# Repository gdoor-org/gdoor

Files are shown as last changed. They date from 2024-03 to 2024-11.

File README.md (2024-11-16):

<p align="center">
GDoor Logo
GDoor Hardware
</p>
<p align="center">
  https://gdoor-org.github.io/
</p>

_________________

The GDoor hardware adapter allows listening and controlling the bus and e.g. integrating a Gira door bell into a <b>smart home</b> like [Home Assistant](https://gdoor-org.github.io/documentation/homeassistant.html) or [openHAB](https://gdoor-org.github.io/documentation/openhab.html). It might serve as an DIY alternative to the Gira TKS-IP-Gateway. It supports the following features:

- (In development): Audio support via VOIP
- listening to the bus, e.g. to trigger notifications on mobile devices when a door bell button is pressed
- sending to the bus, e.g. to open the door

Receiving and sending video is currently neither supported nor plannend.

GDoor is a project to collect and document findings about the Gira Door System, all figured out by reverse engineering.
Contributions are welcome!

# Buy / DIY
Moved to the dedicated [page](https://gdoor-org.github.io/buy.html) on our homepage.

# Documentation / Home Automation
Moved to the dedicated [page](https://gdoor-org.github.io/documentation/getting-started.html) on our homepage.

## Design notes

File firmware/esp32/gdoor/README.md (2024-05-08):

# ESP32 Firmware
More information about the firmware are located on the
[GDoor Homepage](https://gdoor-org.github.io/documentation/firmware.html).

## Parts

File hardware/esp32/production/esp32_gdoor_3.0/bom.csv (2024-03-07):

Designator | Footprint | Quantity | Value | LCSC Part #
C1 | 0603 | 1 | 47n | C1622
C10 | 0603 | 1 | 1n | C1588
C11, C13, C15, C16, C5, C6, C7 | 0603 | 7 | 100n | C14663
C12, C14 | 0603 | 2 | 10u | C96446
C2, C4, C8, C9 | 0603 | 4 | 100p | C14858
C3 | 0603 | 1 | 10n | C57112
D1 | SOIC-4_4.55x3.7mm_P2.54mm | 1 | MB10S | C2488
J1 | anschlussklemme2x1 | 1 | Screw_Terminal_01x02 | C8385
Q1 | SOT-23 | 1 | MMBT5401 | C8326
Q2 | SOT-23 | 1 | MMBT2222A | C8512
R1, R20 | 0603 | 2 | 130k | C22795
R10, R15, R6 | 0603 | 3 | 18k | C25810
R11, R13, R2, R22 | 0603 | 4 | 10k | C25804
R12, R14 | 0603 | 2 | 2k4 | C22940
R16, R17, R5, R7 | 0603 | 4 | 5k1 | C23186
R18, R19, R3, R4 | 0603 | 4 | 82k | C23254
R21 | 0603 | 1 | 4k7 | C23162
R8, R9 | 0603 | 2 | 47k | C25819
U1 | SOT-353_SC-70-5 | 1 | TLV9351 | C4367425
U2, U3 | SOT-23-5 | 2 | LMV321 | C7972
U5 | SOT-89-3 | 1 | HT7533-1 | C14289

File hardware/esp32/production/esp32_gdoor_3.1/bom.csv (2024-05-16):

Designator | Footprint | Quantity | Value | LCSC Part #
C1 | 0603 | 1 | 47n | C1622
C11, C13, C15, C16, C17, C3, C5, C6, C7 | 0402 | 9 | 100n | C307331
C12, C14 | 0603 | 2 | 10u | C96446
C19, C20 | 1210 | 2 | 100u | C15008
C2, C4, C8, C9 | 0603 | 4 | 100p | C14858
D1 | SOIC-4_4.55x3.7mm_P2.54mm | 1 | MB10S | C2488
D2 | D_SMA | 1 | SS14 | C2480
J1 | steckklemme2x1_1 | 1 | PlugIn_Terminal_01x02 | C8387
J2 | PinHeader_2x10_P2.54mm_Vertical | 1 | ESP_left | C7501280
J3 | PinHeader_2x10_P2.54mm_Vertical | 1 | ESP_right | C7501280
J5 | nofoorprint | 1 | Plugged into C8387 | C8466
Q1 | SOT-23 | 1 | MMBT5401 | C8326
Q2 | SOT-23 | 1 | MMBT2222A | C8512
R1, R20 | 0603 | 2 | 130k | C22795
R10, R15, R22, R33, R6 | 0603 | 5 | 18k | C25810
R11, R23, R24 | 0603 | 3 | 10k | C25804
R12, R25 | 0603 | 2 | 2k4 | C22940
R13, R29, R31, R8 | 0402 | 4 | 10k | C25744
R14 | 0603 | 1 | 1k | C21190
R16, R17, R5, R7 | 0603 | 4 | 5k1 | C23186
R18, R19, R3, R4 | 0603 | 4 | 82k | C23254
R2 | 0603 | 1 | 22k | C31850
R26, R27 | 0603 | 2 | 4k7 | C23162
R28, R30, R9 | 0603 | 3 | 47k | C25819
R32 | 0603 | 1 | 100k | C25803
R34 | 0603 | 1 | 0 | C21189
U1 | SOT-353_SC-70-5 | 1 | TLV9351 | C4367425
U2, U3 | SOT-23-5 | 2 | LMV321 | C7972
U6 | SOIC-8_3.9x4.9mm_P1.27mm | 1 | LM393 | C7955

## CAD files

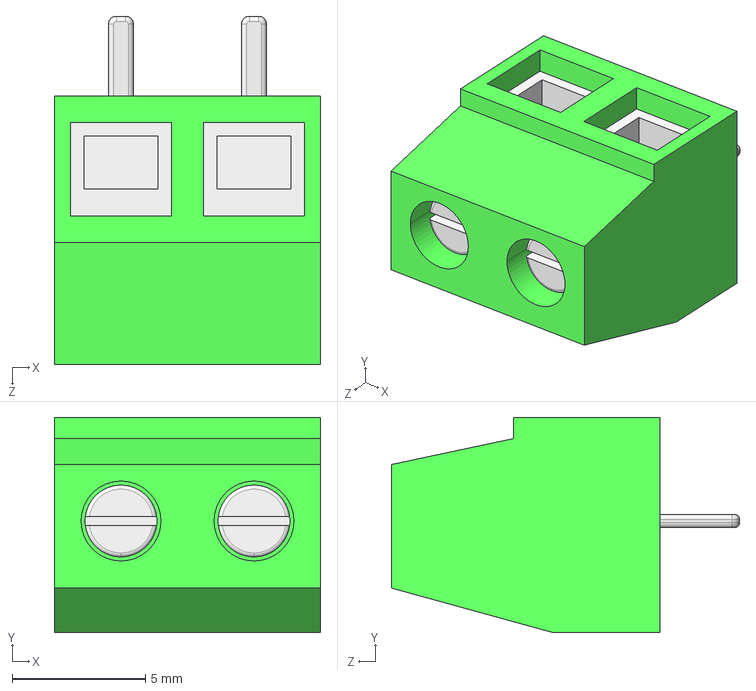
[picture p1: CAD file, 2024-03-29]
hardware/esp32/3dmodels/User Library-WJ127-5_0-2P.step
10.0 x 8.10 x 13.1 mm

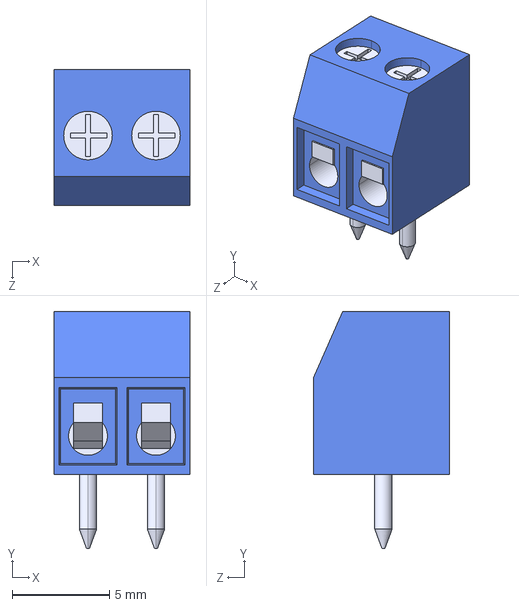
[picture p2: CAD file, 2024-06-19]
hardware/esp32/3dmodels/screwterminal_3_5mm_2.STEP
7.00 x 12.2 x 7.00 mm

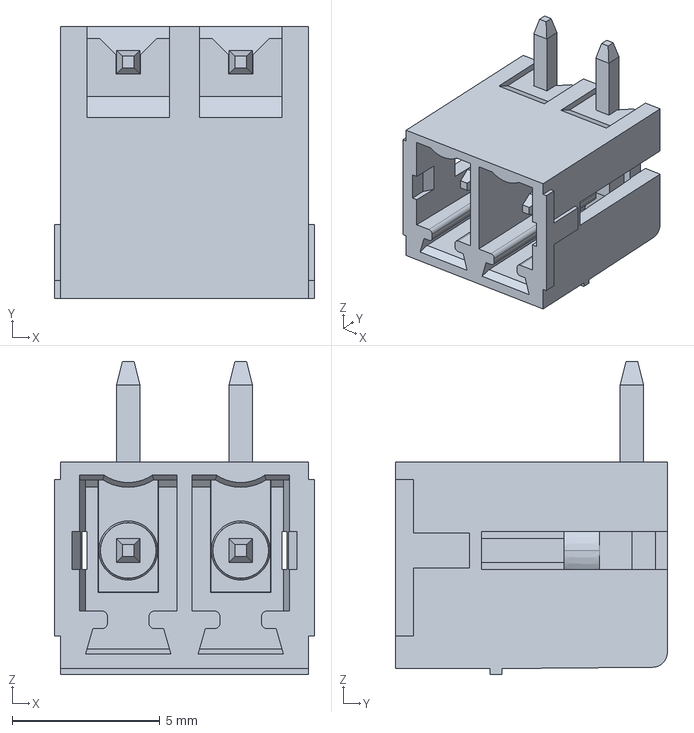
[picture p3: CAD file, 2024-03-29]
hardware/esp32/3dmodels/screwterminal.stp
8.81 x 9.20 x 10.6 mm

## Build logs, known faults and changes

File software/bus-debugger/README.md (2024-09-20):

# mqttlisten (For linux)

Small python helper script, to show GDoor messages.
It connects to the MQTT server and displays the messages.

To setup all needed libraries use `./bootstrap.sh`,
afterwards you can run it via `./mqttlisten` (for options, see `./mqttlisten --help`).

grafik

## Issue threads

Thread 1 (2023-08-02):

How to build an Gira Bus <-> Smart Home adapter

jschroeter, 2023-08-02:
Hello,
Thanks a lot for your efforts on documenting!

I’m looking for a (self-made) solution to open our house door via Home Assistant. I know there are commercial solutions like Gira TKS-IP-Gateway. But it’s too pricy.

I’m wondering if you could give me some guidance on how to build the hardware to connect to the bus? I’m a software guy, don’t know much about hardware. But e.g. I’m a bit familiar with ESPHome.

Thanks and have a nice day!

DaSchaef, 2023-08-02:
Hi :-)

I have two working solutions, but they are still comparable complicated and need at least some knowledge about electronics.

The easiest thing is just listening to the bus. This can be done with little hardware.
Controlling the bus is more complicated.

And the most complex situation is reading/writing bus and beeing supplied by it (as it is "hard" to not disturb it).

I have a custom build PCB by JLCPCB which can do all of that, but  bus supply is working only "border line" according to my measurements.
I know what roocky mistake I made but never corrected it, this is why I did not publish it.

So there are two ways:
- ESP way, few parts, easy to build: Needs knowledge and probably an oscilloscope to fine tune the voltage levels (I never finished the "simple" design ).
- STM32 way, fully custom PCB working with few acceptable bugs (should not be powered by the bus itself, but 5V USB works well): Needs knowledge about JLCPCB, some soldering, STM32 programming (JTAG) ...

I would be happy to build a solution together with someone, document it for the public - but sadly there is some electronics knowledge required - as I fear it wouldn't work first try.

Is there anything where you would feel comfortable with? if you bring in the time, effort and willingness I can support it. But this is no easy solution. Sorry :-/

jschroeter, 2023-08-21:
Hi, thanks a lot for your quick answer and sorry for my late reply.

Before I continue, another question: is the protocol somehow encrypted? Or can I "simply" listen what command is sent when I open the door via the indoor device and re-send this command later again to open the door? Or how would I find out the dst?
I was reading regarding possible alternatives and found the [NUKI Opener](https://nuki.io/de/opener/) which sounds promising, but it's not officially compatible with Gira. Also [they claim Gira uses an encrypted bus](https://developer.nuki.io/t/opener-with-gira-ap-system-55/2914/2). With [some additional device from Gira it seems to be working](https://developer.nuki.io/t/nuki-opener-with-gira-ap-and-turkommunikations-tasterschnittstelle-2fach-121000-or-unterputz-schaltaktor-121100/4287).

DaSchaef, 2023-08-31:
Sry I forgot your message, was on vacation.

The bus is not encrypted at all. From an electrical standpoint it is just a bit complicated and Nuki is too simple for that. Cheap excuse from whoever 😅

The addresses can be sniffe with the same hardware d and values just copied to your own commands. You could even brute force it but the bus speed is a natural barrier, it would take weeks and why wait 😄

Of course you can just salvage an indoor station.
There are different revisions but I think the Nuki thread should give a good start.

DaSchaef, 2023-08-31:
Ah what you would be able to also do: replace the pic microcontroller on a original indoor station with an esp.

The existing microcontroller just receives and sends out PWM signals, each on a dedicated pin. The pwm is just the digital version of the signals I show in this repo.

 But I have no turn-key solution so that would be maybe even more complicated. And more costly.

ravenst0ne, 2024-02-15:
Hey @DaSchaef , really nice work!
May I ask which HW you used to generate the signals with an ESP32 and what's the difference compared to the STM32 solution? Also how you powered the controller using the power from the bus line would be interesting.

I have STM32 and ESP32 available and would like to give it a try after listening to the bus with an oscilloscope.
Powering with external 3,3/5V is not a problem, better have cables in front of the front door than having to walk to the door each time :)

DaSchaef, 2024-02-16:
Hi :)

I never beautified my project because:
1. I finished my goal
2. Continuing would have meant re-spin PCBs (money)
3. Receiving money would mean an obligation for a project which I only play with part-time
(not good).

This is why I search people who are able to proceed where I finished, and I'm fully willing to support it, but time and money I don't want to finish it myself :)
I just uploaded my internal, ugly stm32 design.

1.
Bus powering: Do not do it, without really knowing electronics ;-)
If you really understand my shitty schematic, we can discuss it in more details.
But believe me, there are audio and EMC related issues.

2.
RX is most easiest:
You can use something like, AC coupling the signal to a GPIO.
But limit the voltage with low-forward-voltage diodes (e.g. Schottky),
to not damage the GPIO in the rare case that a large voltage transient is coupled
to the GPIO.
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

After that you can use EXT Interrupts and Timers to decode the signals.
Logic should be simple, I should be able to help you:
In principle:
Use EXT INT to count the pulses inside a pulse train,
Use a TIMER/ALARM to see if a pulse train is finished (xx ms no EXT INT means pulses are over).
Add the pulse counts to an array.

If your timer fired and there are no counts (which means the timer fired twice in a row), you know that the whole transmission is over.
Think of the timer similar to a watchdog, where the EXT INT resets it.

Now you have an array with pulse counts, see the image on the GDOOR main repo.
You can then process this further to bits (>50 counts = start bit, >25 counts = Bitvalue is 0, <20 counts = Bitvalue is 1), and then you have a 01010010 bitstream, which you can
pack into 9 bit words, check or ignore parity bit, remove it, and now you have 8 bit value (aka chars).

3. TX is complicated,
I successfully breadboarded two possibilities:
3.1 First options was a Wien-Oscillator which I was able to turn on and off by a GPIO.
3.2. I think more easier is a bandpass: Just output the needed signals as a PWM, the bandpass will "make it a somehow nice sine trains", like shown in the top README.md.
A bandpass example with added output buffer is shown in the stm32-ugly.

4. Uploades STM32 design:
You should be able to procure the hardware pre-assembled from JLCPCB,
all assembly info are inside the schematic.
You need KiCAD with the "Fabrication Toolkit" PlugIn, this combo will create you production files, which you can upload to the JLCPCB webpage and they will produce, assemble and ship the PCBs.

At least, that is what I did a year ago.
Be aware of the two bugs I documented! They are still included!

1. Crystal Osc. Pinout is wrong, this should be corrected, otherwise you have a hard time
to manually correct this error (which means fine soldering needed!).
From my memory I swapped the meaning of the pins.

2. Remove R15, best is to set it to DNP (Do not populate) for JLCPCB,
this will disable self-powering from the gira bus, but leaves you with the options to power via the USB-C connector. (The whole board only needs ~ 10mA, at 5V this would be 0.05W)

Be also aware of the strange form factor: You can break-out the two circled PCBs, so that
the finished assembly fits into an "Unterputzdose" (German).

DaSchaef, 2024-02-16:
On thing I forgot:
The STM32 version is rock solid in RX and TX, only with the bugs (which I fixed manually) and the "strange" form factor.

DaSchaef, 2024-02-23:
I just uploaded a ESP32 version.

It can be produced by JLCPCB, 5 parts costs approx. 30€ (shipping and taxing increases price).
I currently have no firmware for this. If we have enough interest, I can order it.
(Everyone can order these as well, you can use the production subfolder in esp32).

Additionally needed are:
- ESP32mini
e.g. https://www.az-delivery.de/en/products/esp32-d1-mini
- Pin Headers to connect/solder the ESP32 to the PCB
(if JLCPCB should solder pin headers it increases price by I would assume 20-30€
just for these).
- Firmware

If someone else (or I) order a batch, I can offer to write a simple firmware for it.
No full guarantee that there is no hardware bug in the design, but as I copied
it from the working STM32 PCB, risk is low.

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

ravenst0ne, 2024-02-23:
Unfortunately I didn't have the time yet to check your latest commits, but they look quite very interesting!

I'm totally interested in ordering such sample, feel free to contact me via mail for further details :)

jschroeter, 2024-02-23:
Same, I'm also interested. Let's sync via mail.

DaSchaef, 2024-02-25:
I created a private repo, due to missing mails and no DM capability on Github :-)

Closed 2024-04-02.

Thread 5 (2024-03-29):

Add high-level props to JSON output

jschroeter, 2024-03-29:
To allow comfortable automations/triggers in Smart Home platforms like Home Assistant.

Suggestion for new fields:
- action: doorBell / floorBell / openDoor / ...
- param: which button was pressed
- deviceType: doorStation / indoorStation / controller
- source
- destination

DaSchaef, 2024-03-30:
We can re-use (and migrate to class based C++) from the STM32 code:
https://github.com/gdoor-org/gdoor/blob/a9e28f83e366b4aa6abce5f1029c4be776966766/firmware/stm32-ugly/Core/Inc/gdoor_protocol.h (and corresponding C file)

DaSchaef, 2024-04-01:
Can you test #6 ?
I expect that it will **not** work on first try, as it is a dry run implementation,
with significant refactoring in the RX logic.

Additionally this should also fix #4 without the big ArduinoJSON library dependency.

DaSchaef, 2024-04-03:
Closed in #6

Closed 2024-04-03.

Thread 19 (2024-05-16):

Spare bus adapters

nholloh, 2024-05-16:
Does anyone, preferably from Germany, have a spare bus adapter lying around?

If not, I may proceed with an order. If you're looking to source one through me, feel free to leave a message here.

DaSchaef, 2024-05-16:
Germany is no problem. I do not need an adapter, but I can support if needed.

Please note:

1. Currently the V3.1 (latest version) is not in a release file or production folder.
You need to create the JLCPCB data from KiCAD (there is also a JLCPCB plugin which I use).
If needed, I can create the production files.
2. The version 3.0 had some bugs, which we hope to have fixed in 3.1, but we did not produce 3.1 yet.
We changed:
- Way smaller board, more dense, more tiny parts.
- We changed the bus connector from a screwing type to a plugin-type.
JLCPCB should ship a matching cable end together with the boards, but we have not yet tested if this is really the case :)
- The powering scheme is changed a bit
- We implemented a fix for receiving the data, via comparator
- We increased the sending amplification.

So all in all, I think it should work, but as its the first run for 3.1, there is a risk that we may find other bugs.
I can assure that I can try to support it - we got all v3.0 boards working :)

jschroeter, 2024-05-16:
I‘m interested in getting a V3.1 adapter and then would have a working V3 one for sale in case someone is interested.

DaSchaef, 2024-05-16:
If there is interest, I can offer to do the JLCPCB procurement again - to test the PCBs here on my test setup.
If you share the cost, and I can keep one for development? (same as 3.0)

nholloh, 2024-05-16:
@jschroeter I'd be up for 3.1 as well. @DaSchaef sounds good to me!

DaSchaef, 2024-05-16:
I created a private repo, so that we can better exchange non-public data.

mrtnkhl, 2024-05-17:
@DaSchaef I would be interested in a 3.1 unit as well, my Gira setup is a bit more complex and could be interesting for testing in a larger install.

sim-san, 2024-05-30:
@DaSchaef
I found this just this morning. I have a gira door communication and and home assistant server. I would like to help you testing the board.

DaSchaef, 2024-05-31:
I'll contact you. We have one last adapter available.

github-k8n, 2024-06-19:
Anyone had any luck ordering from JLCPCB? they seem to currently be out of stock on the connector .. if anyone has done or wants to do another run ordering these, I'd be in..

DaSchaef, 2024-06-19:
See #29 :-)

DaSchaef, 2024-10-09:
Could you please look into #36 and give me feedback about stability (details are in #36) - the more people test, the better.
This would help me to free up some I/Os for audio support. No firmware update needed, only a setting in the web interface of GDoor.

ix2, 2024-12-17:
Hi, I am interested in buying a board. If @dtill  have one available I am really interested. BTW, my location ist Germany (Ruhrgebiet). How to handle it?

Shoomaan, 2024-12-17:
I‘ve got 4 Boards ( 3.1 )to sell.
Shipping from Germany
12€ / each  + Shipping

dtill, 2024-12-17:
@Shoomaan  i'll take one as well :) let me know how!

> I‘ve got 4 Boards ( 3.1 )to sell. Shipping from Germany 12€ / each + Shipping

ix2, 2024-12-18:
@Shoomaan I have just send you a message on your 'Kleinanzeigen' ad. Would like to take two of the available boards.

Mr-Taxman, 2025-01-18:
> I have a four 3.1-1 available. Let me know if you're interested.

Would like to buy one, but how? Any standard procedure paypal friends?

Thanks Christof

ATell-SoundTheory, 2025-01-18:
> I have a four 3.1-1 available. Let me know if you're interested.

For those interested, please send an email to atell at soundtheory.com. Shipping is from Germany. Preferred payment is PayPal and I can also provide an ESP32mini with the GDoor PCB.

cbka, 2025-03-29:
> > I have a four 3.1-1 available. Let me know if you're interested.
>
> For those interested, please send an email to atell at soundtheory.com. Shipping is from Germany. Preferred payment is PayPal and I can also provide an ESP32mini with the GDoor PCB.

i have 3 left (Kit with ESP32)

SoleroTG, 2025-05-04:
@ATell-SoundTheory, @cbka, or does anyone else have a spare kit for shipment in germany?

Luckymoep, 2025-05-04:
Hi,
does anyone have a spare to sell? I am located in Germany...
@cbka do you have one left?

dtill, 2025-05-04:
> Hi, does anyone have a spare to sell? I am located in Germany... [@cbka](https://github.com/cbka) do you have one left?

yes, have a look on Kleinanzeigen for "gdoor"  ;)

cbka, 2025-05-04:
Message ID: ***@***.***>Yes :-) 2 übrig

maxliem9, 2025-06-04:
@cbka I am also interested. Also located in Germany.
You may send me an mail? max.liem.public@gmail.com

debergi, 2025-06-29:
Does anyone have another one laying around that I could buy? Maybe someone from Germany

maxliem9, 2025-06-30:
@debergi , yes. I have 4 sets with the ESP32 mini.
I am from Germany. Send me your email and I will contact you with more info.

maxliem9, 2025-06-30:
Or just me an Email to max.liem.90@gmail.com

dagroe, 2025-08-21:
Does anyone still have one to spare or is interested in a pooled JLCPCB order?

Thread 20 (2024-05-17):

Audio Support

mrtnkhl, 2024-05-17:
There is currently no audio support planned until reverse engineering and interfacing with the digital bus is fully working. Creating this Issue as a placeholder for possible future work and to inform others who might be looking for audio (and video) support.

Per @DaSchaef the audio (and video signals) are modulated onto the wire in an analog format. It is suggested but has not been verified through testing that connecting a headphone amplifier via a coupling capacitor to the bus would yield audio signals. Likewise, connecting a line-out to the bus could allow sending audio signals to the (door) station. It is important to understand that analogue audio (and video) signals are only present after the digital bus command has been sent to the respective station to transmit audio (or audio and video) on the wires that also transport the digital bus signals.

See https://gdoor-org.github.io/documentation/protocol.html "Request Audio", "Request Video" for more details on the respective bus messages.

Since is (unfortunately) no digital audio (or video) signal are present, a combination of an ADC and DAC, most likely connecting via I2S to the ESP32 is needed to convert the analog signals to the digital domain. Using an ADC, DAC and a Raspberry Pi could be an option as well but this would require too many resources and power.

Per @DaSchaef, on the ESP32 side, there is additional work needed, mostly in software, like working with the DMA engine, timing Wifi transmissions correctly, etc.. This work can be summarized in the categories of coupling, digitizing, processing and streaming to an endpoint, e.g. via SIP or RTSP. If one wanted to have bidirectional, parallel communication, with the other (door) station some analog circuit magic to prevent audio feedback loops would be needed as well.

mrtnkhl, 2024-05-17:
https://github.com/sikorapatryk/sip-call

Some previous work has been done using an ESP32 with an ADC and DAC as a SIP client, so maybe this can be of use here.

mrtnkhl, 2024-05-17:
https://github.com/vvigilante/comelit-simplebus1

Another similar project but for Comelit, including the analog circuits interfacing with the ESP32 ADC and DAC for audio:

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

mrtnkhl, 2024-05-17:
See this thread for a similar discussion for a Comelit system:
https://github.com/Elektroarzt/simplebus2-mqtt-bridge/issues/3

DaSchaef, 2024-06-06:
I successfully received audio via my computer:
- I just connected a cheap USB audio dongle to the bus (after the diode bridge, so that I do not need to care about polarity). (So that if something get's damaged it is only the cheap USB dongle)
- I used Audacity to record the audio from the USB dongle
- I send `AUDIO_REQUEST` via the GDoor v3.1 hardware adapter to my outdoor station
- I talked in front of the station

My voice was easily recorded on the computer.
So I can confirm that bus audio is just plain simple analog "line audio".

I would not recommend this setup so far, as for a real usage more protection and also a bit of filtering is needed.
In real world usage there would be multiple issues:
- The connected audio may disturb or "weaken" the bus signals
- The bus signals may damage the USB audio input

(both easily solvable)

After doing a lot of research:
- ESP video is a project in its own, we would solve problems which do not need to be solved.
Even if we realize a solution (external ADCs etc), they will not be long lasting, as chip availability may change etc.
- ESP audio may be possible, but as video is not possible, let's just make *one* adapter.

My feeling is we should continue the audio and video route by just making plain simple adapters.
Kind of "bus to cinch analog video" and "bus to cinch analog audio".
These signals can be digitized with ~10€ USB Dongles and a Raspberry Pi, which itself can then act as VOIP phone,
image sender or whatever is needed.

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

DaSchaef, 2024-06-06:
I have no Gira equipment here to test video. (if someone finds a cheap used video outdoor station *g*, indoor is not needed for tests, we know how to request video ;-) )
So my raspberry pi solution / hat would be a "blind try" regarding video.

mrtnkhl, 2024-06-08:
@DaSchaef do any of the Comelit circuits posted above look useful? It seems like they have bus-coupled audio ADC/DAC working and code for it as well on the ESP32 platform?

mikburnz, 2024-10-06:
door opener works perfect. instead of 2 way audio it would be helpful to send one predefined message to the speaker. So i can advice the delivery to store items in front of my door f.e. Any suggestions if we can realize that?

DaSchaef, 2024-10-07:
This should be doable as well,
I need to find a bit of time for it to make a ESP hardware. Currently I'm (very slowly) working on understanding ESP audio system. The most work is in the firmware/software, less in a hardware adaption.
I want to first understand what is needed and also doable in firmware/software so that the hardware does not lack a functionality needed.
(If we find someone with deep (!) ESP audio knowledge, better experience, it could speed this up. )

DaSchaef, 2024-10-10:
Everyone who is interested and brave (it is very early alpha!),
please tell me, I'll create a private repo to exchange infos about price/payment etc.
Currently I'm still doing the PCB layout and final schematic checks.

mrtnkhl, 2024-10-13:
I would be interested! ESPhome has audio support, e.g. to play out audio files. Maybe that would be an easier start?

jschroeter, 2024-10-13:
I'm also interested!

HJoentgen, 2024-10-19:
Im also intereseted. I will ne installing the Gira system next week

DaSchaef, 2024-10-21:
PCBs arrived today, now I need to test the firmware for audio support (which will also take a bit of time). I will keep you updated.

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

DaSchaef, 2024-10-21:
I got a partly success, but it seems the ESP board is too weak (not enough memory) for the VOIP audio code.
Next I'll try with a WROVER module instead of WROOM, it can be patched to the existing PCB. ESP documentation is really bad :-1:

https://www.amazon.de/dp/B09Z2GCCJZ

DaSchaef, 2024-10-22:
With the new board I got a first voip connection (without being able to check audio so far). So at least the ESP code has no RAM memory issues anymore.

Testing VOIP via my FritzBox did not work, but it think the error is my FritzBox VOIP settings.
Next step will be to setup a local debug VOIP Server so that I can start to test audio and debug also with server side logs.

mrtnkhl, 2024-10-22:
@DaSchaef super cool! Kannst Du etwas ins Detail gehen, was Du in v4.0 vom Board hinzugefügt hast und wie das Setup aussieht auf der HW und SW Seite?

DaSchaef, 2024-10-24:
Currently I'm using above shown custom PCB + the above ESP (Amazon Link) connected via jumper cables
(looks way more complicated than it is, it is a simple connection, no soldering or whatsoever).

I can now call my FritzBox from the ESP (GDoor Adapter). Audio is not working yet - this is now the next step.

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

Software is based on Esspressif ADF (https://github.com/espressif/esp-adf), I'm working in a private repo at the moment, as it is still very early/ugly, unstable and not working :) I'll merge it in the branch here once I'm sure that it is at least barely usable.

DaSchaef, 2024-10-24:
For feature/HW changes in the v4.0 HW:
- I removed the variable RX threshold (because the Pin was needed for audio), only a fixed threshold is supported.
This does not affect the user.
- I added a DC measurement of the bus voltage (so we can detect if bus is powered/connected).
- I added an ES8374 codec, which should make the audio in/out
- I added more on-board power filtering for the audio part
- I added a lot of debug pads related to the audio part

mrtnkhl, 2024-10-24:
@DaSchaef very exciting! Thanks for the update!

DaSchaef, 2024-10-28:
I'm still struggling with audio, currently I only get silence in both directions - currently it looks like the S/W ist the reason and not the H/W. At least GDoor and VOIP seem to work in parallel. The ESP audio libs are a mess, but it is very slowly progressing - next step will be a small audio test script - not from the ESP libs, but from scratch - to have a minimal example to debug the missing audio. :sweat_smile:

DaSchaef, 2024-11-01:
Still no audio but I have an assumption:

The audio codec needs a MCLK generated by the ESP32.
On the older ESP32 (incl. my boards here) can only output the precision MCLK on IO0,
which I designed in HW. But it seems the ESP boards use IO0 themselves for their "Bootloader Button",
therefore it can not be used although it is accessible on the pin header. :rofl:

From my research the newer generation ESP32S3 is able to freely route high precision clock outputs to any of the GPIO.
So next try will be with yet another ESP board https://www.amazon.de/gp/product/B0CQNB74R9

DaSchaef, 2024-11-10:
Good news, audio via VOIP is working.

I'll give more details about shipment next week. We need to try this in more installations before finalizing.

You will need:
- GDoor Adapter 4.0
- Jumper Wires Female to Female  (https://www.amazon.de/Heevhas-Breadboard-Female-Female-Steckbr%C3%BCcken-Drahtbr%C3%BCcken/dp/B0D91C4GF2)
- ESP Board (https://www.amazon.de/dp/B0CQNB74R9)

1. I will document the connection GDoor to ESP Board (via the jumper wires) in the next days.
2. You need to solder a small bridge (very easy) so that the ESP board outputs the 5V from USB to the GDoor Adapter 4.0
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

DaSchaef, 2024-11-10:
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

Connection Scheme

mikburnz, 2024-11-10:
Awesome! Waiting for shipment instructions

stich86, 2024-11-11:
this is a good news
do you think, after a reverse, if possible to include Urmet 2Voice BUS support to your product?

It's a 2-wire bus not polarized (running at 48/50V), and for sure video and audio are analog.

Thanks in advance for your amazing work!

DaSchaef, 2024-11-11:
Hi all, I added the people interested to a private repo, I will create a issue there.

@stich86
Please make a separate issue and give a bit more details about the bus, Let's discuss there.
My first impression would be try it with a USB audio interface first :)

jschroeter, 2024-11-15:
The Amazon link to the ESP board stopped working?

DaSchaef, 2024-11-16:
https://www.amazon.de/dp/B0CYZVQR27

manustaufi, 2025-02-02:
> [@mikburnz](https://github.com/mikburnz) [@HJoentgen](https://github.com/HJoentgen) [@jschroeter](https://github.com/jschroeter) Please check for the Github Invite, check the issue in this private repo and give feedback there or via mail. So that I can send out this week. :)

Could I also get an invite please? I’m planning to buy the v4 version for audio support. If you have a spare one available, kindly let me know :)

DaSchaef, 2025-02-03:
Currently all are already gone, and the current Audio hardware is sending audio too weak (not loud enough).
I'm very busy on work, so it will take quite some time.

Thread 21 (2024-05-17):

Video Support

mrtnkhl, 2024-05-17:
There is currently no video support planned until bus protocol reverse engineering is done and interfacing with the digital bus is fully working. Creating this Issue as a placeholder for possible future work and to inform others who might be looking for video support.

Details concerning possible Audio support are tracked in Issue https://github.com/gdoor-org/gdoor/issues/20.

Per @DaSchaef there is sufficient evidence to assume that video is transmitted in analog just like the audio part of the communication with the (door) station in a resolution of roughly 320x240 pixels (or respective lines) per @jschroeter . It is assumed that an ADC would be needed to convert the analog signals to digital for the ESP32 and then send them via SIP/RTSP/RTP to a destination on the network. Issues outlined in https://github.com/gdoor-org/gdoor/issues/20 apply, in addition to those the extra bandwidth needed to digitize the video signal from the wire is going to be of concern.

mrtnkhl, 2024-05-17:
See this thread for a similar discussion for a Comelit system:
https://github.com/Elektroarzt/simplebus2-mqtt-bridge/issues/3

mrtnkhl, 2024-05-17:
https://www.eevblog.com/forum/projects/ic-for-capturing-composite-video-screenshot/

mrtnkhl, 2024-05-17:
https://github.com/wooky/esp32-analog-video-over-wifi

https://github.com/11tools/esp32cvbscam

jschroeter, 2024-05-17:
I can confirm that the resolution is 320 × 240 since the images saved on the SD card of the indoor station do have that resolution. They are saved as BMP files but I guess this is irrelevant.

jschroeter, 2024-05-17:
A bit off topic, but while I was setting up mobile notifications when someone hits our door bell I noticed that the Home Assistant mobile apps supports attaching a camera image/stream to the notification: https://companion.home-assistant.io/docs/notifications/notification-attachments#automatic-snapshots

I initially thought I don't need this, but of course, once I got the adapter running and read this, I immediately thought: that would be cool :-)

DaSchaef, 2024-05-23:
https://github.com/antmicro/cvbs-mipi-bridge
https://github.com/o-murphy/cvbs2rpi

DaSchaef, 2024-06-10:
I have a question to the owners of video installations:

Is the video parallel to the audio conversation?
If yes, the video signal may be modulated and no simple "cinch video", and we would need to find out the modulation scheme.

mrtnkhl, 2024-06-11:
Video and audio are transmitted in parallel. Not sure if audio is duplex but I think it is.

DaSchaef, 2024-06-11:
Hmm, we need someone with a video installation and at 40MHz bandwidth (better 100Mhz) oscilloscope.
We need to record start of video, to identify the video modulation/signal scheme.

I'm not 100% familar with analog video, but from what I understand: the standard CVBS goes down in the spectrum, overlapping with the audio range. So I would assume that the video may be FM (or even AM, but I don't think so) modulated to shift it to higher frequencies.

Or audio / video is interleaved? Don't know if such a thing could work

mrtnkhl, 2024-06-11:
Any recommendations for an affordable USB oscilloscope that would satisfy those requirements? My GIRA system has video.

DaSchaef, 2024-06-14:
I had a quick glance at Video Bus signals.

Sadly they seem to be modulated, over 100 MHz?
I had a bit of trouble with my cheap 100MHz oscilloscope.
It may be over 100Mhz or the cheap scope was crap :wink:

I'll try a SDR solution next time, so that we first can get a feeling about the needed carrier frequency,
and be sure what expected range to measure and that we use the right measurement setup.

As the Modulation may be over 100 MHz it may indicate that standard analog TV modulation is used??
From Wikipedia:
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

DaSchaef, 2024-06-19:
Small status:
I'm still working on this, also on the hardware side of #20
But as I want to combine both, it takes some time. I still need to find time for another round of measurement to get the modulation frequency.

DaSchaef, 2024-06-23:
Update (slow as I do not own a video bus):

I measured today via SDR (hackrf) and couldn't identify the modulation frequency.
This may indicate that the modulation frequency is on some VHF/UHF band where the RF signal  is hidden behind the normal over the air transmission like DVB-T etc.

So I either need to setup a wired coupler for the SDR (without destroying the sensitive SDR RF input) or I need to use the way more expensive oscilloscope (which I tried to avoid :wink: ).

So:

Easy option one (cheap oscilloscope): :-1:
Easy option two (SDR with Antenna): :-1:

meeh, its getting more complicated :sweat_smile:

mrtnkhl, 2024-06-23:
You got this! Curious to hear how they did it!

CENGOiSM, 2024-07-17:
I recently came across this project and wanted to express my gratitude for your work 🙏. While I’m not particularly knowledgeable about the electronic aspects, I found this FAQ that describes the frequencies used to transmit video:

https://partner.gira.de/service/faq/antwort.html?id=939

Center frequency **8 - 12 MHz**
Sidebands **+ / - 5 MHz**

Maybe this information might be helpful to you.

DaSchaef, 2024-07-17:
Wow, yes this is very helpful.

It indicates some problems during my oscilloscope trials.
Dual Sideband with +- are also a good thing. If it would be AM with both sideband this may ease demodulation significantly. No VSB like old time TV transmission reduces demodulation effort.

Let's see when I have access to a video system again. I'll test. Thanks!

DaSchaef, 2024-07-24:
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

We have first data, it should be a checker board :)

It is FM modulated, at  ~11MHz.
PAL, 625 , 25 FPS (these settings worked)

The demodulator in SDRangle is great but rather limited to analyze. This needs more custom software to better understand and also learn what is needed in hardware.
So it will still take time, no fast progress to be expected.

mrtnkhl, 2024-07-24:
GDoor's moon landing!

CENGOiSM, 2024-07-25:
Wow, great news! Would it be beneficial to share a 10-60 second segment of the transmitted signal so more people can analyze its integration potential through simulation?

DaSchaef, 2024-08-04:
A short status, I'm still - slowly in the free time - working on video.
Uploading is a bit hard:
- I have no good capture yet
- Raw data even for seconds is in GByte range, this is a raw data steam.

I was able to decode a noisy color video, so it is normal PAL, FM modulated at 11 MHz.
Next step is to get a better data capture and get a clean software decoding to finally understand all parameters necessary for a usable solution (e.g. is there a deemphasis necessary?).

DaSchaef, 2024-09-15:
I did progress further and did more research, simulation and tries in the past time.
My conclusion is to not proceed on the video side for the moment.
I'll move to audio, but do not expect fast progress, it is in my free time.

The problem with video is to find the best combination of the following requirements, which are hard to combine:
1. Cheap: max. 100€, as otherwise it comes closer to used TKS gateways.
2. Easy: As a hobby project, the people need to assemble themselves and number of units is very tiny.
3. Future proof: Of course there are solutions, but it does not make sense to design one,
where chips, inductors or similar are not available anymore in half a year (fast moving EEE market).

In principle there are two points to solve:
- FM demodulation, where the bandwidth is rather high compared to the modulation frequency
(where requirement 3 is had to reach without FPGA, which violates 1 and 2)
- Digitize the baseband signal without FPGA (which would violate requirement 1 and 2 for hobby users).

In the past there were rather easy solutions, which are still available on the used marked (analog TV tuner chips, cheap PLLs etc), but this would violate 3. These solutions are not produced anymore, since already quite some time.

Going the "direct" computing solution would mean, to e.g. reprogram a suitable SDR device (e.g. I digitized it with the hackRF one clone, ~ 100€). But this again needs another computer, or a custom firmware.

I think a solution could still be possible, but it is not fun to solve these two main problems with the 3 requirements.

mrtnkhl, 2024-09-16:
@DaSchaef shall we close this issue then or would you like to keep it open?

kripton, 2025-01-03:
Hi, also if this is closed, I would like to give my 2 cents, including some background.
I own a Gira system (no video camera attached), including their TKS-IP-Gateway and some Gira G1 connected via Ethernet. The TKS-IP-Gateway sits on the bus and is able to act as a SIP-server to stream audio AND video to connected clients when someone rings the door.
The flash chip of the gateway is flaky and forgets some bits if not written for some time, resulting in boot failures. For details, see https://www.mikrocontroller.net/topic/531261. Since I was plagued by that, I digged into their bootloader (which changed between firmware v4 and v5 from RedBoot to uBoot and was able to fix my gateway (twice!) and the gateways of two other people who sent me theirs.
However, this is not a good long term solution and I was thinking to replace the gateway's digital/Linux part with something custom and keeping their bus/analog PCB. Thank god I found your project! Perfect substitution for the expensive and buggz TKS-IP-Gateway!

Since I made some pictures of their PCBs, I can share that their TKS-IP-Gateway uses the Sanyo LA9520 chip to demodulate the video. Supports audio as well. Receiver: https://www.alldatasheet.com/datasheet-pdf/pdf/40415/SANYO/LA9520V.html, Transmitter: https://www.alldatasheet.com/datasheet-pdf/pdf/40414/SANYO/LA9511W.html

If we could source that (or a similar chip), video might be a lot easier to do.

Does someone have some spare gdoor v4 adapters or is a group-buy planned the next time? I would definitely be interested, even though I'm more a fan of the RP2040 than the ESP32 ;)

DaSchaef, 2025-01-15:
Thank you! :)

The LA9520 seems to be obsolete or not produced any more.
The video ADC part is an TPS something from Ti, as far as I read on microcontroller.net :)
If really needed, I think I can find the exact part number.

For group buying, please se #19

Closed 2024-09-20.

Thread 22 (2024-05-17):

DIN Rail Mount

mrtnkhl, 2024-05-17:
To mount the gdoor adapter in an electrical panel next to other Gira intercom components, a 3D printed case that fits onto a DIN rail would be great.

DaSchaef, 2024-05-17:
Here is a 3D render of v3.1
Additionally to the bus connector, either the USB port or 5V pads (shown as holes in the step export) are needed for power.

Height is not 100% sure, as the ESP32mini is plugged into the v3.1 adapter.
[v3.1-step.zip](https://github.com/gdoor-org/gdoor/files/15355771/v3.1-step.zip)

DaSchaef, 2024-10-10:
Please reopen if needed, I currently do not work on it.

Shoomaan, 2024-12-18:
Just a quick design: edited some DIN Rail mount from thingiverse to fit the gDoor Bus Adapter with ESP32 mini on top.
Any ideas for better cable outlet are welcome

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
[gDoor-housing.zip](https://github.com/user-attachments/files/18177081/gDoor-housing.zip)

DaSchaef, 2024-12-28:
Thank you! :)

In future, we can also update the PCB  but currently my time is rather occupied with the audio stuff. We hav a first beta hardware, but there are still bugs to fix first. And it will still take quite some time.

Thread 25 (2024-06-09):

Options for Home Assistant integration

nholloh, 2024-06-09:
Currently, home assistant integration is done through MQTT with [auto discovery](https://github.com/gdoor-org/gdoor/pull/18). However, in my opinion, the integration in home assistant still offers potential for optimisation:

1. Identifying bus messages to trigger various functions (door open, light, ...) is rather tedious, having to search through logbook, or by connecting the device via serial to a PC.
2. Triggering the functions currently has to be done by performing a service call to either echo something through the serial connection or perform a service call to send an MQTT message to a predefined topic, which carries just the bus message that was previously recorded.
3. The esp32 chip cannot be used for anything else, even though it might have resources to spare. That is, some people may find it useful to have it set up as bluetooth proxy for BLE devices, to extend home assistant's bluetooth coverage.

I believe there are multiple ways to address these issues.

I am currently exploring one of them, creating an `external_component` for esphome based on the gdoor code. In my opinion, esphome offers several advantages:

1. it provides an easy way to configure the rx related settings in the device's yml
2. it can provide an out-of-the-box feature to switch into a learning mode, where bus messages for certain actions (door open, light, ...) can be recorded
3. we can distinct buttons and states for these actions
4. the esp32 chip may additionally be used for something other than just being the gdoor adapter, by simply including that functionality in the device's yml.

For openHAB users I believe there is also a binding to include esphome devices, if desired.

Of course, most of this is also possible with the current firmware and MQTT based approach. However, I personally find the MQTT approach to be more verbose and it may require more knowledge on the user-side to get things up and running. Using esphome, we could reduce it to a couple of lines of yml code, which will be used by esphome to automatically compile the most recent firmware with default settings (of course you can override them) and flash that to the device.

I'd be keen to know any other Home Assistant user's take on this.

DaSchaef, 2024-06-09:
I think OpenHAB will work with either solution, as a OpenHAB user, I'm used to set it up more complicated.
My understanding of esphome is not good enough to judge, but GDoor currently needs multiple timers and interrupt,
don't know how good these low level needs will integrate into a framework.

nholloh, 2024-06-09:
I am just getting into this, however esphome can use esp-idf or the arduino framework to compile, and compilation happens using platformio under the hood.

In the esphome component, you can implement a `setup` and a `loop` function, from which you have quite granular control over whatever it is you need to do. So from an API level perspective, I do not see an issue, actually the API looks quite similar to the `main.cpp` from gdoor. I took an attempt at porting:

```cpp
void GDoorSensor::setup() {
    ESP_LOGI(TAG, "Setting up GDoorSensor");

    // TODO: Make sensitivity configurable.
    GDOOR::setRxThreshold(PIN_RX_THRESH, RX_SENS_MED_NUM);

    // TODO: Make RX PIN configurable.
    GDOOR::setup(PIN_TX, PIN_TX_EN, RX_PIN_22_NUM);

    // Publish initial idle state.
    publish_state(gdoor_data_idle.action);
}

void GDoorSensor::dump_config() {
    ESP_LOGCONFIG(TAG, "GDoor text sensor");
}

void GDoorSensor::loop() {
    GDOOR::loop();

    GDOOR_DATA* rx_data = GDOOR::read();
    if(rx_data != NULL) {
        ESP_LOGI(TAG, "Received data from bus");
        GDOOR_DATA_PROTOCOL busmessage = GDOOR_DATA_PROTOCOL(rx_data);

        ESP_LOGD(TAG, "Data: ", busmessage);

        // Set sensor state.
        publish_state(busmessage.action);

        ESP_LOGD(TAG, "Sensor state set. Back to idle.");

        // TODO: Set sensor state back to idle.
        publish_state(gdoor_data_idle.action);
    }
}
```

From what I understand, timers and interrupts are part of the Arduino framework. Since you can configure esphome to build off the Arduino framework, this _should_(TM) theoretically work pretty much out of the box.

jschroeter, 2024-06-09:
As a HA user, I do like the idea with ESPHome. I haven't done much with it yet but I do like the general concept and I expect it to work nicely. Further, I have the impression that the [WifiManager](https://github.com/tzapu/WiFiManager) is a bit buggy (e.g. it's leaking the Wifi password in the UI, I tried fixing it but couldn't get it to work) and not so well maintained. Mostly from a gut-feeling a think ESPHome is the more future-proof solution.

nholloh, 2024-06-09:
ESPHome is a first party add-on developed by the company that also develops home assistant and HAOS (nabucasa). That is, I expect this to be most future-proof.

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

nholloh, 2024-06-09:
So quick status report: I do have the first version of the firmware _compiling_, but I did need to make some changes to the gdoor code. The most significant being reverting from the v3 arduino framework apis (timer, ledc) to the v2 ones, since, for some reason, platformio has only published v2 versions.

I'll do a test run on my esp tomorrow evening and see if it succeeds in reading messages from the bus.

```
INFO ESPHome 2024.5.5
INFO Reading configuration /config/esphome/gdoor-test.yaml...
INFO Updating https://github.com/nholloh/gdoor-esphome.git@main
INFO Generating C++ source...
INFO Compiling app...
Processing gdoor-test (board: wemos_d1_mini32; framework: arduino; platform: platformio/espressif32@5.4.0)
--------------------------------------------------------------------------------
HARDWARE: ESP32 240MHz, 320KB RAM, 4MB Flash
 - toolchain-xtensa-esp32 @ 8.4.0+2021r2-patch5
Dependency Graph
|-- WiFi @ 2.0.0
|-- ESPmDNS @ 2.0.0
|-- Update @ 2.0.0
|-- noise-c @ 0.1.4
RAM:   [=         ]  12.8% (used 41792 bytes from 327680 bytes)
Flash: [=====     ]  48.1% (used 882081 bytes from 1835008 bytes)
========================= [SUCCESS] Took 15.15 seconds =========================
INFO Successfully compiled program.
```

sim-san, 2024-06-10:
_Reference to https://github.com/gdoor-org/gdoor/issues/27#issuecomment-2157721911_

In the last Release of ESPHome, they also support Events on the ESPHome: [ESPHome HA Events](https://esphome.io/components/event/)

nholloh, 2024-06-10:
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

The integration with esphome itself for just reporting the current bus status seems to be working, however during reverting to the v2 arduino APIs I probably killed the timers involved in decoding the bus signal. I'm rather busy this week so I don't expect to make a whole lot of progress until the weekend. In the meantime, if anybody wants to take a look, feel free to take a look here: https://github.com/nholloh/gdoor-esphome. If you want to make some changes for testing, let me know and I can set permissions accordingly.

Here's the yml I use for testing:
```yml
esphome:
  name: gdoor-test
  friendly_name: GDoor_Test

esp32:
  board: wemos_d1_mini32
  framework:
    type: arduino

# Enable logging
logger:
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
nholloh, 2024-12-18:
Hi all, sorry for being a bit unresponsive lately. So I was unable to complete the esphome integration due to the lack of time on my side. Also I was having a hard time figuring out a proper way to get the esphome yaml validation to work with the structure I imagined. The lack of documentation on the development side of esphome is definitely not helpful. If anyone wants to give it a go I'd be happy to provide my last working version and the non-working version that aims for proper yaml structure. @dtill lets connect somehow once you have received your board and see if we can tinker together to make some progress here.

I'll provide the code latest on the weekend - not sure I'll get to it before that.

dtill, 2025-01-18:
started a esphome custom component: https://github.com/dtill/esphome-components/tree/main/components/gdoor
took @nholloh approach as a start and added and restructured from there. still needs polishing but it works and i think it covers the basic use cases. any thoughts and testing welcome ;)

mrtnkhl, 2025-01-19:
@dtill amazing!!
@DaSchaef, @dtill is there a way to maybe bring this code over into this repo so that code bases can move along together and people find everything in one place?

mrtnkhl, 2025-01-20:
Hi there! I did not get the chance to test yet since I am traveling.

Agree with you that it should be an official esphome component once it is ready for it!

Until then, in the interest of visibility for people that are interested in gdoor and might be able to contribute to making your code esphome ready, it might be helpful to have whatever code we have now in this repo. People could find it easily, add to your work and help with documentation etc. Hopefully that accelerates the path to an official esphome component that we would all love to have.

Looking at @DaSchaef @jschroeter et al as well for their thoughts :)!

dtill, 2025-01-20:
from my side its perfectly fine to integrate it to the gdoor repo.

DaSchaef, 2025-01-20:
I'm happy to get support :-)

What would be best: Do everything here in the repo or create a sub repo?
For action runners etc I would imagine that a separate repo may be better?

When its finished stable, we could switch to it as "main" code and the current code would get "legacy or debug"?

dtill, 2025-01-20:
> I'm happy to get support :-)
>
> What would be best: Do everything here in the repo or create a sub repo? For action runners etc I would imagine that a separate repo may be better?

i'd suggest a seperate repo named 'esphome_components'  with subfolder 'gdoor' (like in my repo) would be good practice. so people can integrate easy with just putting something like

```
external_components:
  - source:
      type: git
      url: https://github.com/gdoor-org/esphome-components
    components: [gdoor]
```
into their yaml files. esphome then grabs the code from github automatically to compile when hitting "install" button in esphome. if maybe one day the component happens to become a part of esphome directly the repo can be kept further for dev version of the component.

allthough it be nice to add a section on the gdoor webpage with some documentation instructions on how to use the esphome component. (i can prepare such a documentation if thats something helpful i can add)

> When its finished stable, we could switch to it as "main" code and the current code would get "legacy or debug"?

the current code is amazing and should always be an up to date working standalone firmware in my opinion.
its really well done! its also very accessible and well thought: the webinstaller and the mqtt setup for a quick device test and was also worth gold while developing for debugging on a second device etc.

i think both codebases, the current gdoor standalone firmware and the esphome component should be maintained in paralell also for upcoming (audio-capable) hardware versions wich first might work on a standalone firmware.

dtill, 2025-01-21:
well.
 i added my gdoor esphome-component to the  repo:
[https://github.com/gdoor-org/esphome-components](https://github.com/gdoor-org/esphome-components)

github-k8n, 2025-01-24:
Thanks dtill for this component, will give it a try immediately.

One small suggestion is regarding whether it would also be possible to add "event" entities.
https://esphome.io/components/event/index.html

That would be a better fit for the (currently used) binary_sensor triggers and as far as i understood HA and esphome are going into that direction as well. (not suggesting to replace them just to also allow to add event components.)

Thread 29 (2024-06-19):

Bus Adapter Procurement Round 3

DaSchaef, 2024-06-19:
As mentioned from @github-k8n  in #19 the bus connectors seem to be unavailable at JLCPCB.
https://jlcpcb.com/partdetail/Dorabo-DB301V_3_5_2P_GNS/C695629 can be a replacement,
but in the current HW Rev3.1 they would collide. Therefore the connector holes need to be moved a bit to the PCB edge.

I'll hopefully release a "Screw Terminal Version" 3.1-s this evening.
If you want to organize a procurement round, feel free to use this issue here :+1:

DaSchaef, 2024-06-19:
Should work now:
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

https://github.com/gdoor-org/gdoor/releases/tag/3.1-1

github-k8n, 2024-06-19:
the 2 unpopulated places in the middle are expected?

DaSchaef, 2024-06-19:
Yes

github-k8n, 2024-06-19:
Ok, ordered 5 , will mention here when they arrive, if they work and then might sell 3-4 for anyone interested (including esp32). Might take a while though (with cheapest delivery option ..)

fabicodes, 2024-06-20:
> Ok, ordered 5 , will mention here when they arrive, if they work and then might sell 3-4 for anyone interested (including esp32). Might take a while though (with cheapest delivery option ..)

I'd be interested in buying one from you then

monnypython, 2024-06-21:
> Ok, ordered 5 , will mention here when they arrive, if they work and then might sell 3-4 for anyone interested (including esp32). Might take a while though (with cheapest delivery option ..)

Hi, I would also like to buy one.

fabermundi, 2024-06-21:
Hello, I would also be interessed.

DaSchaef, 2024-06-24:
For me it looks good, I see the string main+hash in the last images (artifacts).
Thanks alot!

jschroeter, 2024-06-24:
> For me it looks good, I see the string main+hash in the last images (artifacts). Thanks alot!

I guess you wanted to post this in #12

DaSchaef, 2024-06-24:
Ups, yes ^^

rhmunich, 2024-06-30:
> Ok, ordered 5 , will mention here when they arrive, if they work and then might sell 3-4 for anyone interested (including esp32). Might take a while though (with cheapest delivery option ..)

Hello, I am also interested. Would be great if you let me know whether there is still a chance to get one. Thx.

github-k8n, 2024-07-02:
The boards are here and it seems to be working. Unfortunately I did order the wrong ESPs so i don't have those included (just had one of the right ones left over from previous project).
Just the (populated) board for 10 EUR + 5 EUR for packaging/sending  would be my price.
@fabicodes @monnypython @fabermundi , you were the first three and I want to keep two boards so the 3 remaining will go to you.
Not sure how to best proceed here as there is no private chat function.  Maybe if you trust me you can send the 15 EUR WITH your address via paypal (using send to friends to avoid paying extra) to paypal.com@k8n.de and I will send you the board (only the populated board, no esp32 included)
Again, only for the three people referenced above.

fabermundi, 2024-07-03:
> The boards are here and it seems to be working. Unfortunately I did order the wrong ESPs so i don't have those included (just had one of the right ones left over from previous project). Just the (populated) board for 10 EUR + 5 EUR for packaging/sending would be my price. @fabicodes @monnypython @fabermundi , you were the first three and I want to keep two boards so the 3 remaining will go to you. Not sure how to best proceed here as there is no private chat function. Maybe if you trust me you can send the 15 EUR WITH your address via paypal (using send to friends to avoid paying extra) to [paypal.com@k8n.de](mailto:paypal.com@k8n.de) and I will send you the board (only the populated board, no esp32 included) Again, only for the three people referenced above.

Great news. Thank you for that. I've send the money and a mail to the address you sented. Hope you got it.

github-k8n, 2024-07-03:
ok. got the money and the address from all three, will be sending them out today.

For anyone else wanting to start another round, at the moment JLCPCB still has free assembly.

DaSchaef, 2024-07-23:
Is everything working? Can we close the issue?

github-k8n, 2024-07-23:
I guess so, i sent out all three and received a confirmation from one at least and considering i did not hear back from the other two I guess they also arrived.

Now it's just trying to get it to work with esphome which is a completely different issue :D

DaSchaef, 2024-07-23:
in #25 there is some work which we hopefully can integrate, maybe you two can connect?
I'm still working on audio/video. This is a slow process. :)

DaSchaef, 2024-10-09:
Could you please look into #36 and give me feedback about stability (details are in #36) - the more people test, the better.
This would help me to free up some I/Os for audio support. No firmware update needed, only a setting in the web interface of GDoor.

Closed 2024-07-24.

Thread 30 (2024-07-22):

Questions regarding potential risks

CENGOiSM, 2024-07-22:
Assuming one has a non-faulty PCB and ESP32, how likely is it to damage GIRA components?
Naturally, reverse-engineering both the software and hardware design introduces potential incompatibilities and errors.
However, how significant could the impact be on other participants, the bus, or the TKS system in general?

I live in a rented apartment and would love to install gdoor, but I'm currently weighing the associated risks.

DaSchaef, 2024-07-22:
This is a tricky question.

So in principle the bus adapter should not pose any risk, yet there are caveats as in reality it is hard to catch all bus installations:

- The Gira bus itself is short circuit proof.

For the GDoor adapter:
- The GDoor bus adapter uses a diode bridge, so  bus polarity does not matter.
- The interfaces to the bus are AC coupled, so no risk to send a wrong voltage level to the bus.
- Yet it has a certain RX and TX capacitance, by principle, as any other Gira device.
 These should be negligible.
- If your ESP would go wild an send all the time, it could theoretically disturb the bus for all, but not damage it.

There is one connection which may be tricky: The power supply of the GDoor bus adapter:
The bus adapter connects the Ground of the power supply to the ground of the bus.
This should pose no problem ("connect 0V to 0V"), but as a developer we can not know how your Gira installation is done.
Even Gira itself warns about this, as this also may happen in regular installations with their own devices.
e.g. https://partner.gira.de/service/faq/antwort.html?id=1254
Even here, I can not think about a situation were you damage something.

Paranoia mode:
1. Use a isolating 5V supply e.g. MeanWell HDR-15-5, or a USB power supply without earth connection (most of them).
Do not use a computer or similar to power the GDoor adapter.
2. Do not connect to the USB with your computer while the GDoor adapter is connected to the Gira bus.
Only use Wifi.

Please remember this is an open source project with no guarantee. If in doubt you may want to contact a friend/colleague or similar with electrical or electronic background and ask for help on your specific installation.

Closed 2024-07-24.

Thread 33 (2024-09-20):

Bus Protocol

DaSchaef, 2024-09-20:
I found more infos, which we may be able to use to better understand the protocol,
needs time and starring at raw bus messages to see if it may help us :-)

The Gira Homeserver documentation, seems to give good indications:

**Button:**
1=Light
2=Door Opener
16=Call Request
17=Call Accept

**Source Type (needs translation from German):**
160 = Türstation
161 = Wohnsprechstelle
162 = Wohnsprechstelle Hörer
163 = Bussteuergerät
164 = Schaltaktor
165 = TK-Gateway
166 = Zusatzgong/Busläutewerk
167 = Tasterschnittstelle
168 = TKS-IP Gateway
(e.g. 160 is 0xA0 in hex, this matches what we see on the bus for door station = Türstation)

**Switch Actions:**
Wert 0: Es wird auf AUS-Telegramme gefiltert.
Wert 1: Es wird auf EIN-Telegramme gefiltert.
Wert 2: Es wird auf Toggel-Telegramme gefiltert.

**In multiple pages:**
- Aufsatz (Wertebereich 0 bis 31, indicating 5 bits)
- Tastennummer (Wertebereich 0 bis 127, indicating 7 bit)

**KeyLess-In Gerätetyp:**
(Wertebereich 0 bis 7)
0 = Steuergerät oder KeyLessIn Einheiten
1 = Transponder-Leseeinheit
2 = Fingerprint-Leseeinheit
3 = Codetastatur

**KeyLess Index-Nummer:**
(Wertebereich 0 bis 255)

Beispiel: Finger 17, Transponderkarte 22
Codetastatur/Fingerprint-Leseeinheit
Wert 253: F-Taste gedrückt
Wert 254: Ungültiger Index erkannt
Wert 255: Alte KeyLess-In Firmware

**Nah-/Fernfeld (nur Transponder)**
(Wertebereich 0 bis 1)
0 = Fernfeld
1 = Nahfeld

**TKS-Bus Teilnehmer**
1 = Anrufzustände aller TKS-Communicator beenden
2 = Anrufzustände aller sonstigen TKS-Bus Teilnehmer beenden
3 = Anrufzustände aller TKS-Bus Teilnehmer beenden (auch TKS-Communicator)

**Source:**
http://www.hs-help.net/hshelp/gira/v4_7/de/log16936.html and similar pages

mrtnkhl, 2024-09-21:
Translated text below

**Button:**
1=Light
2=Door Opener
16=Call Request
17=Call Accept

**Source Type**
160 = Door station
161 = Home intercom station
162 = Home intercom station (with receiver)
163 = Bus control unit
164 = Switching actuator
165 = TK gateway
166 = Additional chime / Bus ringer
167 = Push-button interface
168 = TKS-IP gateway

**Switch Actions**
Value 0: It is filtered for OFF telegrams.
Value 1: It is filtered for ON telegrams.
Value 2: It is filtered for Toggle telegrams.

**In multiple pages:**
Attachment (value range 0 to 31, indicating 5 bits)
Button number (value range 0 to 127, indicating 7 bits)

**KeyLess-In device type:**
(Value range 0 to 7)
0 = Control unit or KeyLessIn units
1 = Transponder reader unit
2 = Fingerprint reader unit
3 = Code keypad

**KeyLess index number:**
(Value range 0 to 255)

Example: Finger 17, Transponder card 22
Code keypad/Fingerprint reader unit
Value 253: F-key pressed
Value 254: Invalid index detected
Value 255: Old KeyLess-In firmware

**Near-/Far-field (only transponder)**
(Value range 0 to 1)
0 = Far-field
1 = Near-field

**TKS-Bus participants**
1 = End call states of all TKS-Communicator devices
2 = End call states of all other TKS-Bus participants
3 = End call states of all TKS-Bus participants (including TKS-Communicator devices)

DaSchaef, 2024-09-25:
More findings:

### Fun Fact:
The video indoor station(s) seem to show more menu option, when the whole bus is in programming mode.

### Hardware Types (Indoor, ourdoor etc):
Above values seem to fit. I think we can extend the type list.

### VIDEO_REQUEST
- Param0:
  - Bit0: Turn Light in Outdoor camera off
  - Bit1: Set video frequency in Param1
- Param1: Video Frequency, if Bit1 in Param0 is set

### BUTTON_RING, BUTTON_LIGHT, DOOR_OPEN
- Param0: Most likely button number (and maybe attachment number, see above).
- Param1: 0x60 for normal press, 0xA0 for long press (indicates something in bit 8 and bit 7)

### CALL_INTERNAL
- Param0: Most likely button number (and maybe attachment number, see above).
- Param1: always 0x60 for normal press?

### Button
- Param0: Always bit 7 seems to be set (0x40), lower bits seem to indicate button number (1,2,3...)
- Param1: 0x40 for ON, 0x50 for OFF (currently hard to detect which bits are really used)

Closed 2024-10-10.

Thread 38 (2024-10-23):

Adapters for Sell

marco2901, 2024-10-23:
Hi,

I currently have 4 3.1-1 Boards for sell. Each 12€ plus shipping.

BR
Marco

dschlegel, 2024-10-27:
Hi Marco,
where are you shipping from?
Regards
Daniel

marco2901, 2024-10-27:
Hi @dschlegel,

from Germany. So I could send it as "Warensendung" to you.

BR
Marco

dschlegel, 2024-10-27:
Sounds good. Can you email me at Daniel.schlegel@posteo.net? Then we can discuss the details.

devcomputer, 2024-10-28:
i am very much interested as my landlord just installed brand new 1250, i have HA running and some m5stack EPSs here.
but i do not understand how to connect the gdoor thing to the ap1250?
documentation says:"After successfully setting up the adapter, you can connect it to the Gira TKS Bus."
how? can i just wire it to the two bus cables that are easily accessible or do I need to solder? i dont want to break it and anger the landlord.

DaSchaef, 2024-10-28:
Yes you connect directly to the bus cables and not to the indoor station.
You can connect anywhere, where you have access to the bus cable.
No soldering required on Gdoor side.

Remember, soldering is sadly required for the ESP board which is plugged into the GDoor adapter, as the pin headers do not come pre-soldered (https://www.az-delivery.de/en/products/esp32-d1-mini).

This is the bus connector:
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

Please note, this is an image of v3.1 with a plugable connector,
the new v3.1-1 has only a screw terminal (because of parts availability).

Please also see the warning at the end of the Getting Started page:
https://gdoor-org.github.io/documentation/getting-started.html#h-warning

devcomputer, 2024-10-30:
pretty cool. do i have to use a esp32-d1-mini? i have a box full of AtomS3 Lite ESP32S3 Dev Kits here.
so i would like to buy a board anyway. @marco2901 where is your contactinfo?

DaSchaef, 2024-10-30:
> pretty cool. do i have to use a esp32-d1-mini? i have a box full of AtomS3 Lite ESP32S3 Dev Kits here. so i would like to buy a board anyway.
You may, depending on which I/Os are free, but it will be "ugly" (see my development setup ;-) https://github.com/gdoor-org/gdoor/issues/20#issuecomment-2435736075)

I see multiple options:
- use EspMini, plug and play
- use different ESP32 board (no ESP32Cxyz, only ESP32), connect I/Os via jumper cables.
- use different ESP32 board, recompile firmware to match your available I/O

I recommend ESP32Mini ;-)

marco2901, 2024-10-30:
> pretty cool. do i have to use a esp32-d1-mini? i have a box full of AtomS3 Lite ESP32S3 Dev Kits here. so i would like to buy a board anyway. @marco2901 where is your contactinfo?

Hi, please just let me your mail address here. I will send you the details.

BR
Marco

TilldaKiNG, 2024-10-30:
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

Hi Marco,
I got a new Gira TKS installed today and found this great project. Since i had my old doorbell in HS. I would like the same for the new one. I am from Germany as well an would like to buy a GDoor PCD, if you have stock. You can contact me via huepfen-08-brote@icloud.com thanks!

rstein, 2024-11-08:
Hi @marco2901, I‘m interested in buying a board from you. If you‘ve got any left, please get in touch! 😊
rs_any@icloud.com

Secarius, 2024-11-16:
@marco2901 Do you still have one or two left?

marco2901, 2024-11-16:
Hi @Secarius ,

yes, 2, please send me your contactcdetails (mail).

BR

Secarius, 2024-11-16:
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

Secarius12345@googlemail.com

allgrinder, 2024-11-18:
Hey Marco, I would appreciate an email – shipping would be to Germany. PayPal is welcome.
black-fighters@web.de

Shoomaan, 2024-11-22:
@marco2901
Hi Marco, do you still have one Board left?
If yes, I would be interested in buying one.

devcomputer, 2024-11-22:
oh btw did someone already create a cool case for it? didnt find anything on thingivese.

mrtnkhl, 2024-11-23:
@devcomputer check out https://github.com/gdoor-org/gdoor/issues/22

so far no case has been made but a 3D printed DIN rail case like you can get for the Shelly devices would be amazing. @DaSchaef has linked some step files in the issue, maybe that helps!

lucasheld, 2024-11-25:
@Shoomaan
I have one board left. What's your mail address?

c4ve-d, 2024-12-04:
Hi

I‘m interested in buying a board. Someone got any left?
Since I'm in Germany preferred from Germany (or EU).
Please get in touch!

Thank you in advance

lucasheld, 2024-12-04:
@c4ve-d I'm from Germany and have one board left. What's your email address?

c4ve-d, 2024-12-04:
@lucasheld c4ve@gmx.de

ix2, 2024-12-06:
Hi, I am interested in buying a board. Anybody have one available? BTW, my location ist Germany (Ruhrgebiet).

DaSchaef, 2024-12-17:
I'm closing this one in favor of #19. @ix2 If you still need one, you may look into #19 it seems thre are adapters available.

Closed 2024-12-17.

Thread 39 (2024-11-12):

Extend support to Urmet 2Voice BUS - if possible

stich86, 2024-11-12:
hi @DaSchaef,

I've found your amazing work searching for someone that has tried to reverse Urmet 2Voice BUS.
My intercom is using this system (Urmet is an Italian company that is producing intercom and some other audio\video stuff).

The system is based on 2-wire, non polarized, that runs from 48V to 50V (for very log distance I presume). Each internal unit, without video, is using an STM32G02 as MCU to parse BUS data. There are a row of dip-switches to select the ID and connect up to 4 intercom inside a single apartment.
Audio and video seems analogs (like Comelit SimpleBus), but not 100% sure.

Now my first concern is how to attach the BUS and start reversing it using an oscilloscope.

Do you have any hint?

Thanks in advance for any support!

DaSchaef, 2024-11-12:
I'm aware of multiple modulation schemes, most (SIEDLE, COMELIT) are based on voltage levels, only Gira so far used a "real/RF" modulation like scheme.

For Audio/video you could risk to just connect a cheap USB audio dongle and a raspberry and try it out.

For digital messaging (door opening etc):
I doubt that the GDoor adapter would be able to decode another bus type, it is rather specialized to the Gira modulation.
Nevertheless, I see the possibility, that it may be similar to comelit, where there are also open source projects here on Github.
So you may ask there.

If you want to do it yourself with the oscilloscope it would first be very helpful what exact scope do you have?
Most good scopes have rather high input voltage ratings (100V and more), but cheap scopes may be sensitive.

So:
- What scope do you have?
- What is your level of experience with scopes?

The principle way to do it:
- Find the "Ground" wire, connect the scope ground clip to it.
- Set your scope to "AC" (which often reduces risk of damage)
- Set your scope to 5V/div
- Connect the scope to the signal wire
- Set your Trigger to "Auto", so that you will always acquire data
- Set Timescope to "rather long" while still having a "fast" updated display (so that half a second fits on the screen, roughly)
- A key problem with cheap scope is the dead time: After acquiring data, the scope needs some milli-seconds (sometimes seconds!!!) until it can acquire new data. So you will have "gaps" and if your interesting data is in a gap, you will not see it.
- The trick ist to generate a lot of data, so that the likelihood to fall into a acquisition gap is very low :)
- Generate Bus messages, look at the scope to get a feeling: Do you see changes in the lines? How high are they? how long do they take?
- Reset your settings: Narrow down vertical (voltage) and horizontal (time)
- Generate Bus messages again, iterate until you have a nice setting
- Now set your Trigger to manual. This means acquisition will start only at a certain event (voltage ramp), select a fitting voltage level and rising or falling ramp (slope).
- Generate a Bus message, this message should now stay on your scope screen. So you can look at it more closely.
- Sometimes you may want the trigger to "Single" instead of normal. So it triggers only once,
any you manually need to re-arm (start) the triggering afterwards.
- Now you can iterate to find settings to capture a nice looking, informative image: Full message, zoomed parts of the message, etc.
Important part is that the signal uses as much "space" on your screen as possible (vertical and horizontal), no "unused" space.

1. If you can share these pictures, we can further see what to do with it.
2. Often you can also export the raw data shown on the screen via USB/Lan: Sometimes this is helpful,
as one can "zoom" into it a full bus message later on etc. (Depends on scope)

But this is a project in its own, I have no Urmet parts and I'm currently working on the Audio support here for the Gira bus.
I can only partly support you.

DaSchaef, 2024-11-22:
Please reopen as needed, when you have more information / images.

stich86, 2024-12-01:
Hello,

I've played today with the equipment (found some stuff to create a small lab). Here is an exemple of push "Open door" button.

Any suggestion?

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

DaSchaef, 2024-12-01:
You need more pictures, zoom in, zoomed out.
Such a single picture can not transfer all information. For the full communication it is too short, for the modulation scheme it is too long.

What I find strange is that it looks like there is always an idle oscillation, which would be rather unusual.

stich86, 2024-12-01:
Tomorrow I'll try to do a live capture on an usb stick, may be in audio way so can be analyzed by Audiacity

Yes you are right.. there is some sort of "static" noise on the background. I don't know if it's related to to the cabling or something else..

Closed 2024-12-28.

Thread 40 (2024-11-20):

Issues with adapter 3.1

benoti-git, 2024-11-20:
Hi gDoor Community,
I have recently installed a gDoor adapter v3.1 and connected it to HA. Everything works fine, but I have 2 issues and would like to get your advice.
1.  The device disconnects from WiFi (FRITZ!Box) after 12-24h. No regular pattern visible. How can I debug this, is there a logfile on the adapter to find out what is the cause.
2. When picking up the audio via Türstation, I have a very loud buzzing sound in the background. When I disconnect the adapter from the bus, all is fine again. I also tried shielded cables for the bus connection, but no change.

thanks for your support, Ben

DaSchaef, 2024-11-20:
1. May be related to 2, you can enable debug mode via the web page, this will results in debug messages printed via USB.
2. This may be mains voltage 50 Hz(maybe you can check via smartphone, typically it is 50 Hz or multiple of it), it would indicate that you somehow created a ground-loop.
This would mean you would need to check:
- Do you have an isolated USB power supply, maybe try different USB supplies
- Is the USB bus not connected while normal operation (to not create a ground loop via the USB connector)
- Is the USB power supply on the same phase as the Gira Controller

I would first concentrate on point 2, because point 2 may also be causing distortions on the GDoor PCB as well.
Not all points above are necessary but they help to reduce potential issues.
You may want to test and power the GDoor temporarily via a USB power bank / Battery, the buzz should be gone if no other USB is connected.

(If nothing above helps there may be further solutions which would required hardware changes on the GDoor adapter to test/improve)

benoti-git, 2024-11-22:
@DaSchaef: thanks for the hints. I have used a usb powerbank to connect the wemos and the buzzing is gone. Will try different power supplies next and hopefully find a suitable one. If not, I will see if I can use another phase than the one of the Gira controller.

DaSchaef, 2024-11-22:
Ok, so it seems to be in the power supply or earth/neutral connection.
Maybe a common mode choke like balun may help you as a filter as well.
No guarantee that it will help, but there is a good possibility.

1. Use a core and wrap around the bus wires before connecting it to the GDoor adapter.
2. Another (or additional) possibility is to use it around the USB cable

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
You see, how the cables are wrapped around parallel, not twisted!

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
Another example with clip on core.

The core can be easily purchased, e.g. first amazon link:
https://www.amazon.de/Innfeeltech-Schwarz-Rauschunterdr%C3%BCcker-Kabelclip-Innendurchmesser/dp/B0D3ZYTMHL

benoti-git, 2024-11-23:
@DaSchaef thanks again for the tips. I rewired everything and changed both usb cable and power supply. Using a good old apple power supply did the trick. Now I don’t have any noise on the audio channel anymore. No need to use the core, but this would have been the next step, even had one at home.
really looking forward to the audio development. This will make the use of the adapter even better. Thanks for your hard work on this development!!

benoti-git, 2024-11-25:
I still have not found a solution for the regular outage of the gdoor adapter. After changing the power supply I had thought that it would have solved the regular connection losses, but they now reoccured... I still have not figured out how to get debug messages via MQTT. I activated the debug mode in the menu, but where can I retrieve the respective debug messages via MQTT or check the log file on the ESP itself. Could you please help me here. Thanks

DaSchaef, 2024-11-25:
Debug messages are only send out over the USB port (baudrate: 115200).

benoti-git, 2024-11-25:
OK, I connected it via USB. Where do I find the debug information in the data stream?
Here is what I get via serial: {"action": "BUS_IDLE", "parameters": "0000", "source": "000000", "destination": "000000", "type": "TYPE_GDOOR", "event_id": "1"}.
I will now wait for the adapter to disconnect again and hopefully find a useful debug info then...

DaSchaef, 2024-11-25:
During a reconnect there should be more output, as now also die Wifi Library is in debug mode
https://github.com/gdoor-org/gdoor/blob/feb611d1c08d6f1e54a5dbc9a58bdd9572465d75/firmware/esp32/gdoor/src/wifi_helper.cpp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

While the connection is stable it should be rather quiet, only the IDLE / HomeAssistent Keepalive packets will show up.

devcomputer, 2024-11-25:
same here. 3.1 usb powered and it discconnects after X hours with no pattern.
idle packages show up. I have to unplug and replug device to get gdoor back.

another problem is the IP. cant change it using DHCP or anyhting. once it picked an IP in my LAN it wont take any other IP no matter what IP the DHCP tries to assign the next time.
any solutions to that?

DaSchaef, 2024-11-25:
For Wifi, we use WifiManager, I think we need debug logs of connection (DHCP issue) an disconnect to dig deeper.
(FYI: https://github.com/tzapu/WiFiManager)

DaSchaef, 2024-11-26:
More "ideas" I had:
- I had problems in the past with "weak" china ESP boards (meaning unstable power supply leading to unstable WiFi).
- I had problems with multiple APs broadcasting the same SSID. ESP itself was sometimes (not always!) confused and sometimes connected to weak signal APs.
- When we loose WiFi connection, maybe the WifiManager falls back into the "configuration mode", opening a STA-AP (ESP access point), resulting in a downtime longer than needed (I could not observe this on my own, but maybe its happening).

benoti-git, 2024-11-27:
OK, the issue with connection loss reoccurred today and I can now compare Mqtt and Serial output.
Here is what I see in the log:

Serial Output:
GDoor-Serial  wechselte zu {"debug": "MQTT lost connection"}
10:55:11 - Vor 9 Stunden

MQTT:
GDoor Adapter Bus Data  wurde nicht verfügbar
10:55:22 - Vor 9 Stunden

While there is no more output via MQTT after this connection loss, the serial adapter continues to do something. Here's an extract of the log - this sequence was triggered multiple times as the event_id counter goes up from 31 to 131 in only 4h!

Maybe this helps to find a root cause...

GDoor-Serial  wechselte zu {"action": "BUS_IDLE", "parameters": "0000", "source": "000000", "destination": "000000", "type": "TYPE_GDOOR", "event_id": "31"}
15:37:01 - Vor 5 Stunden

GDoor-Serial  wechselte zu {"debug": "MQTT_PRINTER read()"}
15:37:01 - Vor 5 Stunden

GDoor-Serial  wechselte zu {"debug": "MQTT_PRINTER publish()"}
15:37:01 - Vor 5 Stunden

GDoor-Serial  wechselte zu {"debug": "Output bus data via Serial and MQTT, done"}
15:37:01 - Vor 5 Stunden

GDoor-Serial  wurde unbekannt
15:37:01 - Vor 5 Stunden

GDoor-Serial  wechselte zu {"debug": "MQTT_PRINTER read()"}
15:37:01 - Vor 5 Stunden

GDoor-Serial  wechselte zu {"debug": "MQTT_PRINTER publish()"}
15:37:01 - Vor 5 Stunden

GDoor-Serial  wechselte zu {"debug": "Received data from bus"}
15:37:01 - Vor 5 Stunden

GDoor-Serial  wechselte zu {"debug": "Gira RX was successfully parsed"}
15:37:01 - Vor 5 Stunden

GDoor-Serial  wechselte zu {"debug": "Gira RX done"}
15:37:01 - Vor 5 Stunden

DaSchaef, 2024-11-27:
> event_id counter goes up from 31 to 131 in only 4h!
This may be normal because GDoor send keepalive (or tries to send them) to tell HA that it is alive.

Your log is missing any deeper debug messages, no output from WiFiManager.
Please attach full log over the time (best as txt). I have no high hopes, as the deeper log messages are somehow missing.
Do you record them via HA? Maybe HA filters them out because I would assume they are no valid JSON.
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
DaSchaef, 2024-11-28:
Sorry I'm no HA user, and as an embedded linux developer,  my toolchain is rather "complicated" :-/

From my memory typical programs are:

On Windows: Hterm
On Linux:
- GUI: gtkterm
- Console: `screen /dev/device baud-rate`

benoti-git, 2024-11-28:
I also checked the HA log and found another hint. The HA log shows an issue to set the state starting at 16:09 with 105 repeats, until at 18:10 the adapter finally loses connection and the mqtt-based entity shows the following:

GDoor Adapter Bus Data  wurde nicht verfügbar
18:10:28 - Vor 2 Stunden

Logger: homeassistant.helpers.entity
Quelle: helpers/entity.py:1211
Erstmals aufgetreten: 26. November 2024 um 16:09:20 (105 Vorkommnisse)
Zuletzt protokolliert: 18:10:24

Failed to set state for sensor.gdoor_serial, fall back to unknown
Traceback (most recent call last):
  File "/usr/src/homeassistant/homeassistant/helpers/entity.py", line 1211, in _async_write_ha_state
    hass.states.async_set_internal(
  File "/usr/src/homeassistant/homeassistant/core.py", line 2373, in async_set_internal
    state = State(
            ^^^^^^
  File "/usr/src/homeassistant/homeassistant/core.py", line 1817, in __init__
    validate_state(state)
  File "/usr/src/homeassistant/homeassistant/core.py", line 246, in validate_state
    raise InvalidStateError(
homeassistant.exceptions.InvalidStateError: Invalid state with length 867. State max length is 255 characters.

DaSchaef, 2024-11-28:
This seems to be that HA tries to parse some debug output from GDoor and fails - maybe?

benoti-git, 2024-11-28:
I have now disabled the debug mode in the adapter and I now get a lot more messages via serial. Very strange, but I will now wait until the disconnect reoccurs, maybe I will see some useful info then…

xlemassacre, 2024-12-03:
I think I have the same problem. Can I somehow support with the analysis

DaSchaef, 2024-12-03:
I need the "wm:" debug messages from the serial debug console.
Hopefully we can track it down, at least I hope that we can identify what the ESP chip is "thinking" why it lost connection.

xlemassacre, 2024-12-03:
I need to check if i'm able to connect it to usb for that.

Didn't see any pattern yet. Happened once after running for 2-3 weeks. Last time it happened already after a few days.

benoti-git, 2024-12-03:
On my end I did not experience an outage of the adapter since turning off the debug mode. In the meantime I believe it’s the debug mode itself in combination with HA that leads to a strange behavior and produces all these strange messages via serial and finally freezes the adapter. With debug disabled, I only see correct messages via serial and mqtt and no freezing anymore. Problem solved for now.

xlemassacre, 2025-01-01:
I think I found the reason/pattern now.
I reboot my wifi access points once per month (and sometimes after a firmware upgrade). It seems that after the reboot gdoor is not able to reconnect to the wifi (all other clients are able to renonnect after the reboot).

Is it possible that there is an issue in the software with wifi reconnect handling?

jschroeter, 2025-01-08:
I can confirm issues with Wifi reconnect: when I turn on the wifi time schedule of my router, e.g. that it turns Wifi off during night, it happens that GDoor doesn't reconnect when Wifi is on again.
I assume that it's caused by the [WiFiManager](https://github.com/tzapu/WiFiManager) library we use and it seems that there are ways to fix it: https://github.com/tzapu/WiFiManager/issues/1588
But before investing time we should check proogress of https://github.com/gdoor-org/gdoor/issues/25, in case we tend to switch to ESPHome we should check how Wifi reconnect is handled there.

DaSchaef, 2025-01-15:
I would need serial logs of this, so we can narrow it down. I think it is important that the GDoor is reliable and stable, therefore we should have a stable baseline. But I can not reproduce it here with my FritzBox Wifi on/off (but I know such things from other ESP projects, so yes I understand how frustrating such things can be).

xlemassacre, 2025-01-26:
No worries. Getting the logs that way from gdoor is a bit complicated with my setup/available devices.

As there is a lot of progress currently going on with the esphome custom component I'm looking into that direction and will switch to that as soon as possible.

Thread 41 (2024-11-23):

Interference on Indoor Station Video

allgrinder, 2024-11-23:
Hier ist die Übersetzung ins Englische:

Hi,

I received my board yesterday and immediately connected it to the bus. It was a quick and dirty setup, but I am receiving messages from the bus. Some messages might be duplicated, but overall, it works so far.

Now to my problem: As long as the ESP32 and the board are powered on, the video image on my indoor station has interference. Once the ESP is powered off, the image is perfect again. What could be causing this?

Best regards,

DaSchaef, 2024-11-23:
Please see #40 I think it is the same issue: Ground loop (Brummschleife).
Test it with USB power bank to ensure that this is the case.
If yes, you can correct via different USB power supply, electrical phase, install GDoor closer to the video controller and/or a self build filter as shown in the issue.

allgrinder, 2024-11-23:
Yes, indeed, everything works perfectly with a power bank! Thank you.

Do you have a link for a suitable power adapter?

DaSchaef, 2024-11-23:
Sadly no, it may also really depend on the electrical installation. A generic solution is filtering the power supply,
via Common Mode Choke / Balun / "Gleichtakt-Drossel" (which Gira also builds into its devices,
but we can not implement it, because of parts availability at JLCPCB).
Luckily these filters can be implemented DIY without soldering etc (see #40 for examples).
Some power supplies also implement these filters.

I would suggest:
First try different supplies you already have.
If possible also try different power sockets / locations (phases).
If nothing helps, DIY a filter, you can either filter at GDoor bus connection and/or USB supply,
you need to try.

I would love if you can give feedback, so we can document it - I "sadly" have no problems on my bench setup for development. And in case nothing works I can support further, check the filter etc.

DaSchaef, 2024-11-23:
Looks like a good supply, worth a try - but still I can not say for sure that it will work.

DaSchaef, 2024-12-03:
Did you have a chance to check already? Can we close it?

allgrinder, 2024-12-07:
Not done yet…

allgrinder, 2024-12-13:
With the power supply linked above, I have no issues. However, I also haven’t connected a ground

DaSchaef, 2024-12-17:
Ok and thanks for the feedback, I'll close. If there are problem, just reopen :)

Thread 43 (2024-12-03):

Home Assistant (Yellow) Serial Command Issues / Config Update

mrtnkhl, 2024-12-03:
https://gdoor-org.github.io/documentation/homeassistant.html

**Sensor configuration documentation**

Correction for typo needed, documentation currently reading:
```
sensors:
   - platform: serial
     name: "GDoor"
     serial_port: /dev/ttyUSB0 # change device if needed
     baudrate: 115200
```

Should read  (sensor instead of sensors):
```
sensor:
   - platform: serial
     name: "GDoor"
     serial_port: /dev/ttyUSB0 # change device if needed
     baudrate: 115200
```

**Sending command via serial**
Does not work on Home Assistant Yellow (HAOS). Sensor works when config corrected as per above, but sending command via serial not possible. Running latest audio beta firmware.

configuration.yaml
```
shell_command:
  gdoor_open_street: echo -e '020031ECF3EB0060A103C27A3D' > /dev/ttyACM0
  gdoor_open_courtyard: echo -e '020031ECF3EB0060A11A2F76BD' > /dev/ttyACM0
```

Error in log
```
Logger: homeassistant.components.shell_command
Source: components/shell_command/__init__.py:95
integration: Shell Command (documentation, issues)
First occurred: 11:16:44 (5 occurrences)
Last logged: 11:21:29

Timed out running command: `echo -e '020031ECF3EB0060A103C27A3D' > /dev/ttyACM0`, after: 60s
Timed out running command: `echo -e '020031ECF3EB0060A11A2F76BD' > /dev/ttyACM0`, after: 60s
```

jschroeter, 2024-12-27:
Thanks, I fixed the typo in https://github.com/gdoor-org/gdoor-org.github.io/pull/4

I guess the not working sending over serial is just related to the WIP audio firmware, @DaSchaef?

DaSchaef, 2024-12-28:
Correct, the audio firmware can not send as documented currently.

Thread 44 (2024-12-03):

Feature: Allow sending commands via MQTT or HTTP

mrtnkhl, 2024-12-03:
It would be great to be able to send commands to the Bus via MQTT or HTTP in addition to being able to send via serial. Particularly when there is no computer close to the gdoor adapter/ESP32, sending commands via network would be ideal.

Maybe sending of the commands could be implemented in two ways:
- raw, send any raw command to the bus
- per function: e.g. open door, with the necessary parameters
- per slot (see new SIP firmware), allow configuration settings to be added per slot that allow the identification of the door to open per slot and then just the slot with command open can be requested via network

DaSchaef, 2024-12-03:
MQTT sending is already implemented. Also in audio firmware and should work. If not it is a bug in the audio beta.

mrtnkhl, 2024-12-03:
@DaSchaef awesome, do we have some generic documentation for that? It seems openhab documentation has it, but I am not familiar with openhab

mrtnkhl, 2024-12-03:
https://gdoor-org.github.io/documentation/openhab.html

From what I can gather from the above to send a command to the bus you have to publish to topic "gdoor/bus_tx".

The payload is unclear. Is it 'formatBeforePublish="020031ECF3EB0060A11A2F76BD"' or is it just '020031ECF3EB0060A11A2F76BD' or is it a JSON?

DaSchaef, 2024-12-03:
We need to improve MQTT documentation yes.

The topic is correct (it is the default value, you can change it in the web interface) and just send raw, the `busdata` json entry of the received message you want to send.

At the moment I do not know what the bus message `020031ECF3EB0060A11A2F76BD`  means and where it comes from, without decoding it.
But it needs to be the value you received on your bus of the action you want to "clone". This should work.

If it does not work we may have a bug in the beta firmware or the wiring between ESP and GDoor is somewhere wrong.

DaSchaef, 2024-12-03:
Also the serial debug log should show what the GDoor is trying to send:

From sourcecode:
```
GDOOR::send(str_received); // Send to bus if it is not a command
JSONDEBUG("Send: ");
JSONDEBUG(str_received);
```

mrtnkhl, 2024-12-03:
@DaSchaef so I got this to work somewhat in Home Assistant, but something is weird:

YAML to add a dashboard button to send to the bus (opens the door in this case). Note that the topic is "gdoor/bus_tx" not "/gdoor/bus_tx" as one would think from the openhab docu linked above.

```
show_name: true
show_icon: true
type: button
tap_action:
  action: perform-action
  perform_action: mqtt.publish
  target: {}
  data:
    topic: gdoor/bus_tx
    payload: 020031ECF3EB0060A103C27A3D
name: Street
icon: mdi:door-sliding-open
show_state: false
```

Here comes the weird part:

```
show_name: true
show_icon: true
type: button
tap_action:
  action: perform-action
  perform_action: mqtt.publish
  target: {}
  data:
    topic: gdoor/bus_tx
    payload: 020031ECF3EB0060A11A2F76BD
name: Courtyard
icon: mdi:door-open
```

opens the **same** door although the payload is diffent.

Sniffed payload to OPEN DOOR COURTYARD
```
{"action": "DOOR_OPEN", "parameters": "0060", "source": "ECF3EB", "destination": "1A2F76", "type": "INDOOR", "busdata": "020031ECF3EB0060A11A2F76BD", "valid": true, "raw": ["0x3C", "0x20", "0xC", "0x20", "0x20", "0x20", "0x20", "0x20", "0x20", "0xC", "0x20", "0x20", "0x20", "0x20", "0x20", "0x20", "0x20", "0x20", "0x20", "0xC", "0x20", "0x21", "0x20", "0xC", "0xC", "0x20", "0x20", "0xC", "0x20", "0x20", "0xC", "0xC", "0x20", "0xC", "0xC", "0xC", "0xC", "0xC", "0xC", "0x20", "0x20", "0xC", "0xC", "0xC", "0xC", "0x20", "0xC", "0xC", "0x20", "0xC", "0x20", "0xC", "0xC", "0xC", "0x20", "0x20", "0x20", "0x20", "0x20", "0x20", "0x20", "0x20", "0x20", "0x20", "0x20", "0x20", "0x20", "0x20", "0x20", "0xC", "0xC", "0x20", "0x20", "0xC", "0x20", "0x20", "0x20", "0x20", "0xC", "0x20", "0xC", "0xC", "0x20", "0xC", "0x20", "0xC", "0xC", "0x20", "0x20", "0x20", "0xC", "0xC", "0xC", "0xC", "0xC", "0x20", "0xC", "0x20", "0x20", "0xC", "0x20", "0xC", "0xC", "0x20", "0xC", "0xC", "0xB", "0x20", "0xC", "0xC", "0x20", "0xC", "0xC", "0xC", "0xC", "0x20", "0xC"], "event_id": "5", "busvoltage": 25.27}
```

Sniffed payload to OPEN DOOR STREET
```
{"action": "DOOR_OPEN", "parameters": "0060", "source": "ECF3EB", "destination": "03C27A", "type": "INDOOR", "busdata": "020031ECF3EB0060A103C27A3D", "valid": true, "raw": ["0x3C", "0x1E", "0xB", "0x1F", "0x1E", "0x1F", "0x1F", "0x1E", "0x1F", "0xA", "0x1E", "0x1E", "0x1E", "0x1E", "0x1E", "0x1E", "0x1E", "0x1E", "0x1E", "0xA", "0x1F", "0x1F", "0x1F", "0xB", "0xB", "0x1F", "0x1E", "0xB", "0x1F", "0x1E", "0xA", "0xA", "0x1E", "0xA", "0xA", "0xA", "0xA", "0xA", "0xA", "0x1E", "0x1E", "0xA", "0xB", "0xB", "0xA", "0x1F", "0xB", "0xB", "0x1F", "0xB", "0x1E", "0xB", "0xB", "0xB", "0x1F", "0x1E", "0x1E", "0x1E", "0x1E", "0x1E", "0x1E", "0x1E", "0x1E", "0x1E", "0x1E", "0x1E", "0x1E", "0x1E", "0x1E", "0xA", "0xB", "0x1F", "0x1E", "0xB", "0x1F", "0x1F", "0x1F", "0x1E", "0xA", "0x1E", "0xA", "0xA", "0xA", "0xB", "0x1E", "0x1E", "0x1E", "0x1E", "0x1F", "0x1E", "0x1F", "0x1F", "0xB", "0x1F", "0x1E", "0x1F", "0x1F", "0xB", "0xB", "0xC", "0x1D", "0xA", "0x1F", "0xA", "0xA", "0xA", "0xA", "0x1E", "0xA", "0xB", "0x1E", "0xA", "0xA", "0xA", "0xB", "0x1F", "0x1E"], "event_id": "15", "busvoltage": 25.55}
```

DaSchaef, 2024-12-03:
I think you hit a limitation of the Gira bus itself. The door opener used depends on the last BUTTON_RING message.
It is part of the Gira "bus training", when installing the bus.

The controller which operates the door opener relay decides if it opens the door.

https://partner.gira.de/service/faq/antwort.html?id=1268
In German from Gira, they talk about Nebenstellen etc, but in reality it is just a matter how your Gira Setup was configured. If DOOR_COURTYART is your main door opener, it will always fall back to this one:
> Der an den Schaltaktor angeschlossene Türöffner kann nur über die Taste mit dem Schlüssel-Symbol der Wohnungsstation betätigt werden, wenn zuvor von der Türstation der Nebenstelle ein Türruf ausgegangen ist. Zwei Minuten nach dem Türruf (ohne Gespräch) bzw. 30 Sekunden nach dem Türgespräch erfolgt die Umschaltung auf die Hauptstelle.

mrtnkhl, 2024-12-03:
Haha, fun times! Just found that out indirectly by rebooting the whole stack and getting the same result as described above.

Sniffed the bus again and found the payload for the street door that seems to be accepted at all times.

The below was what the firmware came configured with per default. So the documentation might need an update if this is the new default (it uses /gdoor/ not gdoor/)

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

jschroeter, 2024-12-27:
I improved the HA MQTT docs with https://github.com/gdoor-org/gdoor-org.github.io/pull/4.
Could you double-check? And then we can close this issue?

DaSchaef, 2024-12-28:
Thanks :)

Closed 2024-12-28.

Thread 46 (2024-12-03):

gdoor status indication via LED

mrtnkhl, 2024-12-03:
It would be great if the next HW revision would add a couple LEDs or a RGB LED to indicate system status.

Eg to understand if the bus is connected correctly, wifi works, mqtt works etc.

For remote and space constrained installations, this visual indication would be helpful.

DaSchaef, 2024-12-03:
The new ESP32-S3 board of v4.0 has already a RGB LED equipped, but a bridge needs to be soldered and I think we need the corresponding I/O for audio stuff.
For a next iteration (4.1) it is possible to add LED indication on the GDoor PCB itself, in the past we skipped it to make GDoor as small as possible.

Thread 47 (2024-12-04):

Ethernet Interface

mrtnkhl, 2024-12-04:
Often times wiring for the Gira Bus is installed / terminated in metal cabinets (Unterverteilung) which prevent WIFI signals from reaching access points.

Space permitting, it might be helpful to have an Ethernet interface with an RJ45 connector on the gdoor board. That way, an Ethernet cable can be plugged in and no wifi needs to be used. An ESP32 board with an integrated Ethernet interface could be an alternative.

The cherry on the cake would be POE so that only one Ethernet cable is sufficient to power the gdoor assembly. Galvanic isolation and available ports at the board manufacturer could be an issue here.

DaSchaef, 2024-12-04:
If we find someone we may be able to do it, but because of the EMI aspects, this is currently out of scope. Too risky to create distortion of audio/video on the bus.
Main issue is, that we are limited to what EEE parts are available at JLCPCB and I try to select long term available parts,
so that GDoor hardware does not constantly need to be modified to match parts availability.
The audio CODEC is already rather borderline and I assume will create availability issues in the future.

mrtnkhl, 2024-12-04:
POE support would be a nice to have but not critical since a POE to RJ45 and USB C splitter could be used or the ESP32 board be fed via a USB C power supply. If the risk for basic Ethernet to create a ground loop is too high, that's a different story.

Possible Ethernet chipsets could be:

- LAN8720 (RMII)
- RTL8201 (RMII)
- DP83848 (RMII)
- IP101 (RMII)
- JL1101 (RMII)
- KSZ8081 (RMII)
- KSZ8081RNA (RMII)
- W5500 (SPI)

Those seem to be pretty common, especially the W5500 is available in the tens of thousands.

kripton, 2025-01-03:
I do have limited experience with the ENC28J60 from Microchip and more experience with the W5500 from WizNet (both connected via SPI), however on the RP2040, not on the ESP32.
There are also lots of boards combining the two chips, also with the ESP32, of course.
What you need to keep in mind: At least the W5500 comes without a MAC address. So for hobbyists, either make up some random MAC (as virtual machines do), disable WiFi and use its MAC address instead of buy an I2C EEPROM with a MAC address stored on it (Microchip sells them, for example: https://www.microchip.com/en-us/parametric-search/535)

c4ve-d, 2025-01-20:
Hello

I have already dealt with exactly the same topic. The issue of separating the potential can be easily solved with the right hardware: ESP32-POE-ISO by OLIMEX
More info about the board here --> https://www.olimex.com/Products/IoT/ESP32/ESP32-POE-ISO/open-source-hardware

It separates the electrical potential between the network and the ESP chip and uses the supported network controller LAN8710A (LAN8720 compatible) and runs on PoE (or USB power supply).

I just had to include LAN support and change the pins for IO.
The only hardware limitation I have found so far is that on this board the analog outputs are already used by the network chip and therefore the adjustable output has to be omitted.
And yes, it is connected via wires and does not fit natively on the IO pins.

I've already gotten the software to run on the LAN with small adjustments, but I'm faced with the problem that the GDOOR routines only run when the WLAN is connected. If the wifi is not connected but the wired network is connected, the actual GDOOR application does not run. As far as I understand it, it has a logic that checks the wifi connection and the actual software only runs when wifi is active and connected.

Unfortunately, I'm not a software developer and I'm not making much progress in adapting the software. Can someone maybe support me with the needed adjustments?

DaSchaef, 2025-01-20:
Hey, that sounds very good!

Adapting it "cleanly" is a bit of work, because of the WiFiManager library we use :-/

Are you able to compile the software yourself? My idea would be a rather "hacky / hard coded" variant for your needs.
You would loose the web config page

c4ve-d, 2025-01-20:
Hi

Yes, I downloaded the Git repository and then adjusted the configuration (ESP32 library, IO pins, Ethernet).
Then I compiled the software and transferred it to the ESP.

As I said, I'm not a software developer, so nothing pretty but rather quick and dirty with the help of google and trial and error... :-)

I was able to connect the ESP to Ehernet and an IP was obtained via DHCP.

When connected via WiFi, the ESP32-POE-ISO runs and receives data from the Gira bus.

I failed so far with the configuration or disable or whatever of the WifiManager.

DaSchaef, 2025-01-20:
Did you change the code to get the wired ethernet working? I read it that way.

In that case:

1.

https://github.com/gdoor-org/gdoor/blob/main/firmware/esp32/gdoor/main.cpp

Disable all "WIFI_HELPER" related stuff, in case variables are read, just use hard coded content (most settings examples can be seen in https://github.com/gdoor-org/gdoor/blob/main/firmware/esp32/gdoor/src/defines.h)

2.

Now we need to convince MQTT that you have a valid connection:
https://github.com/gdoor-org/gdoor/blob/main/firmware/esp32/gdoor/src/mqtt_helper.cpp

Disable the WiFi connection state check:
https://github.com/gdoor-org/gdoor/blob/feb611d1c08d6f1e54a5dbc9a58bdd9572465d75/firmware/esp32/gdoor/src/mqtt_helper.cpp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

(remove the if case)

You may want to change the code to monitor the wired connection, so that MQTT reconnects, if the wired connection is lost and established later on again.

Hope this helps you 👍

Closed 2024-12-04.

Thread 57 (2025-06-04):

JLCPCB warns about a mismatch in footprint for C19,C20

maxliem9, 2025-06-04:
I wanted to order the PCB from the JLCPCB.
When I added the BOM (bom.csv) and CPL file (position.csv) from the release page, it gives 3 errors/warnings which should be confirmed.

It's the first time doing anything PCB related for me, so I don't know of any side effect, if I would just confirm it.

1) C19,C20: Footprint (1210) does not match the one (1206) in the bom.
2+3) multiple lines in the BOM have been matched to the same part.

Is it save to simply check it and have it ordered and assembled?

Probably you can add that info to the tutorial page on the webpage?

See screenshots attached.

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

maxliem9, 2025-06-04:
Thanks for the quick reply.

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

DaSchaef, 2025-06-04:
Everything looks good and as designed. So I would say you can continue :)

maxliem9, 2025-06-04:
Another quick side question. For Power supply, can I simply use an old phone charger and attach it to the esp mini and that's it?
Could I also run it with an battery?
I want to install it in the wall just behind the gira module. Will this work?

Closed 2025-06-04.

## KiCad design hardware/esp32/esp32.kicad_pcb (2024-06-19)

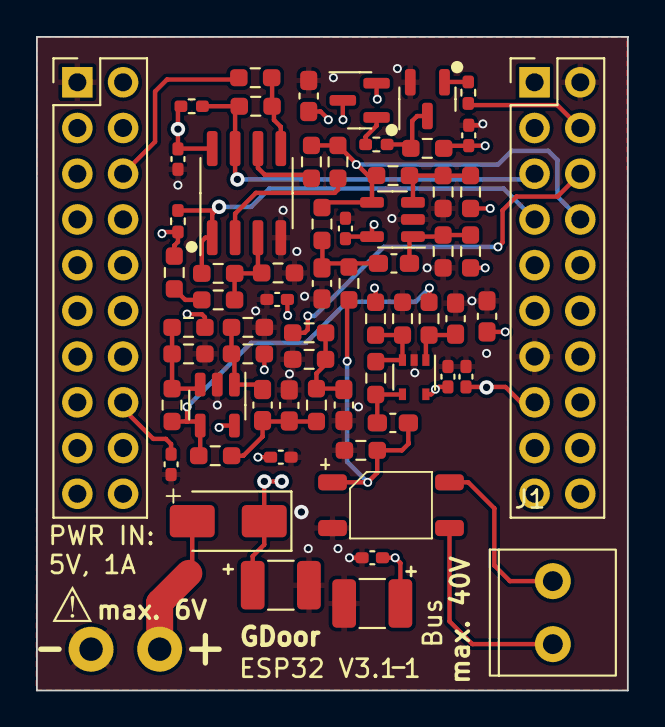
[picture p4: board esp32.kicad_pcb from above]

Board: 4 copper layers, 32.8 x 36.3 mm, 68 parts (1 on the bottom side), 33 nets.

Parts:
C1: 47n; C_0603_1608Metric_Pad1.08x0.95mm_HandSolder
C2, C4, C8, C9, C18: 100p; C_0603_1608Metric_Pad1.08x0.95mm_HandSolder
C3, C5, C6, C7, C11, C13, C15, C16, C17: 100n; C_0402_1005Metric_Pad0.74x0.62mm_HandSolder
C10: 1n; C_0603_1608Metric_Pad1.08x0.95mm_HandSolder
C12, C14: 10u; C_0603_1608Metric_Pad1.08x0.95mm_HandSolder
C19, C20: 100u; C_1210_3225Metric_Pad1.33x2.70mm_HandSolder
D1: MB10S; SOIC-4_4.55x3.7mm_P2.54mm
D2: SS14; D_SMA
J1: PlugIn_Terminal_Screw; anschlussklemme2x1_3_5
J2: ESP_left; PinHeader_2x10_P2.54mm_Vertical
J3: ESP_right; PinHeader_2x10_P2.54mm_Vertical
J4: PlugIn_Terminal_01x02; steckklemme2x1_dnp
Q1: MMBT5401; SOT-23
Q2: MMBT2222A; SOT-23
R1, R20: 130k; R_0603_1608Metric_Pad0.98x0.95mm_HandSolder
R2: 22k; R_0603_1608Metric_Pad0.98x0.95mm_HandSolder
R3, R4, R18, R19: 82k; R_0603_1608Metric_Pad0.98x0.95mm_HandSolder
R5, R7, R16, R17: 5k1; R_0603_1608Metric_Pad0.98x0.95mm_HandSolder
R6, R10, R15, R22, R33: 18k; R_0603_1608Metric_Pad0.98x0.95mm_HandSolder
R8, R13, R29, R31: 10k; R_0402_1005Metric_Pad0.72x0.64mm_HandSolder
R9, R28, R30: 47k; R_0603_1608Metric_Pad0.98x0.95mm_HandSolder
R11, R23, R24: 10k; R_0603_1608Metric_Pad0.98x0.95mm_HandSolder
R12, R25: 2k4; R_0603_1608Metric_Pad0.98x0.95mm_HandSolder
R14: 1k; R_0603_1608Metric_Pad0.98x0.95mm_HandSolder
R21, R26, R27: 4k7; R_0603_1608Metric_Pad0.98x0.95mm_HandSolder
R32: 100k; R_0603_1608Metric_Pad0.98x0.95mm_HandSolder
R34: 0; R_0603_1608Metric_Pad0.98x0.95mm_HandSolder
S1: SYM_ESD_Small; ESD-Logo_6.6x6mm_SilkScreen
U: TLV9351; SOT-353_SC-70-5
U2, U3: LMV321; SOT-23-5
U4: ESP32_mini_no_pads
U6: LM393; SOIC-8_3.9x4.9mm_P1.27mm

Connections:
+3.3V: C6.1, C13.2, C14.2, C16.1, C17.1, C19.1, J2.16 (3V3), R3.2, R5.1, R25.1, R29.2, R31.2, U2.5 (V+), U6.8 (V+)
+5V: C5.1, C11.2, C12.2, C20.1, D2.1 (K), J3.15 (VCC_(USB)), Q1.2 (E1), R9.2
+5Vonoff: C3.1, C7.1, C15.1, Q1.3 (C1), R17.1, R18.2, R33.1, U.5 (V+), U3.5 (V+)
/RX: J3.7 (IO_21/D2/SDA), R28.1, R29.1, U6.1
/RX_ANA: J3.8 (IO_32), R10.1, R12.1, R26.2, R27.2, U2.4
/RX_DAC: J3.5 (IO_22/D1/SCL), R30.1, R31.1, U6.7
/RX_THRESH: J2.6 (IO_26/D0), R22.2
/TX: J3.6 (IO_25), R34.2
/TX_EN: J3.4 (IO_27), R13.2
GND: C2.1, C3.2, C5.2, C6.2, C7.2, C9.1, C10.1, C11.1, C12.1, C13.1, C14.1, C15.2, C16.2, C17.2, C18.1, C19.2, C20.2, D1.2 (-), J2.1 (GND), J3.2 (GND), J3.13 (GND), J4.1, Q2.2 (E), R4.1, R6.1, R7.1, R16.1, R19.1, R21.1, R23.1, R32.2, U.2 (V-), U2.2 (V-), U3.2 (V-), U6.4 (V-)
unnamed: C1.1, R2.1, U.4
unnamed: C2.2, C4.2, R1.2, R10.2
unnamed: C8.2, C9.2, R15.2, R20.2
unnamed: C10.2, R20.1, R21.2, R34.1
unnamed: C1.2, D1.1 (+), R1.1, R32.1
unnamed: D2.2 (A), J4.2
unnamed: D1.4, J1.1
unnamed: D1.3, J1.2
unnamed: Q1.1 (B1), R8.1
unnamed: Q2.1 (B), R13.1
unnamed: Q2.3 (C), R8.2, R9.1
unnamed: R11.1, R14.1, R15.1, U3.4
unnamed: R24.2, R25.2
unnamed: C18.2, R11.2, U.1 (+)
unnamed: R2.2, R6.2, R33.2, U.3 (-)
unnamed: C4.1, R3.1, R4.2, U2.1 (+)
unnamed: R5.2, R7.2, R12.2, U2.3 (-)
unnamed: C8.1, R18.1, R19.2, U3.1 (+)
unnamed: R14.2, R16.2, R17.2, U3.3 (-)
unnamed: R23.2, R24.1, R28.2, U6.3 (+)
unnamed: R26.1, U6.2 (-)
unnamed: R22.1, R30.2, U6.5 (+)
unnamed: R27.1, U6.6 (-)

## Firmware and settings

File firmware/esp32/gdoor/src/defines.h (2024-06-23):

/* 
 * This file is part of the GDoor distribution (https://github.com/gdoor-org).
 * Copyright (c) 2024 GDoor authors.
 * 
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
 * You should have received a copy of the GNU General Public License 
 * along with this program. If not, see <http://www.gnu.org/licenses/>.
 */
#ifndef DEFINES_H
#define DEFINES_H

// GDoor
#ifndef GDOOR_VERSION
#define GDOOR_VERSION "dev"
#endif

#define MAX_WORDLEN 25

// RX Statemachine
#define FLAG_RX_ACTIVE 0x01
#define FLAG_BITSTREAM_RECEIVED 0x02
#define FLAG_BITSTREAM_CONVERTED 0x04
#define FLAG_DATA_READY 0x08

// RX
#define BIT_ONE_DIV 2.5
#define BIT_MIN_LEN 5
#define STARTBIT_MIN_LEN 45

// TX
#define STARTBIT_PULSENUM 66
#define ONE_PULSENUM 16
#define ZERO_PULSENUM 37
#define PAUSE_PULSENUM 30

#define STATE_SENDING 0x01

// WIFI
#define DEFAULT_WIFI_SSID     "GDoor"
#define DEFAULT_WIFI_PASSWORD "12345678"

// MQTT
#define DEFAULT_MQTT_SERVER   "0.0.0.0" 
#define DEFAULT_MQTT_PORT     "1883" 
#define DEFAULT_MQTT_TOPIC_BUS_RX "gdoor/bus_rx"
#define DEFAULT_MQTT_TOPIC_BUS_TX "gdoor/bus_tx"

// Settings

#define PIN_TX 25
#define PIN_TX_EN 27
#define PIN_RX_THRESH 26

// RX Pin Settings
#define RX_PIN_22_NAME "v3.1 adjustable (IO22)"
#define RX_PIN_22_NUM 22

#define RX_PIN_21_NAME "v3.1 (IO21)"
#define RX_PIN_21_NUM 21

#define RX_PIN_12_NAME "v3.0 bugfix (IO12)"
#define RX_PIN_12_NUM 12

#define RX_PIN_32_NAME "v3.0 (IO32)"
#define RX_PIN_32_NUM 32

#define RX_PIN_CHOICES {RX_PIN_22_NAME, RX_PIN_21_NAME, RX_PIN_12_NAME, RX_PIN_32_NAME}
#define RX_PIN_CHOICES_LEN 4

// RX Pin Sensitivity (only working for RX PIN22)
#define RX_SENS_LOW_NAME "Low (1.3V)"
#define RX_SENS_LOW_NUM 1.3
#define RX_SENS_MED_NAME "Med (1.45V)"
#define RX_SENS_MED_NUM 1.45
#define RX_SENS_HIGH_NAME "High (1.65V)"
#define RX_SENS_HIGH_NUM 1.65

#define RX_SENS_CHOICES {RX_SENS_HIGH_NAME, RX_SENS_MED_NAME, RX_SENS_LOW_NAME}
#define RX_SENS_CHOICES_LEN 3

#endif

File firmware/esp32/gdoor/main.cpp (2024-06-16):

/* 
 * This file is part of the GDoor distribution (https://github.com/gdoor-org).
 * Copyright (c) 2024 GDoor authors.
 * 
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
 * You should have received a copy of the GNU General Public License 
 * along with this program. If not, see <http://www.gnu.org/licenses/>.
 */
#include <Arduino.h>
#include "src/gdoor.h"
#include "src/mqtt_helper.h"
#include "src/wifi_helper.h"
#include "src/printer_helper.h"

GDOOR_DATA_PROTOCOL gdoor_data_idle(NULL, true);

boolean debug = false; // Global variable to indicate if we are in debug mode (true)
const char* mqtt_topic_bus_rx = NULL;

/**
 * Function which parses user provided serial input
 * for commands and executes logic based on these commands.
 * @param input String with input from user.
 * @return boolean, true if a command was found, false if no valid command was found.
*/
boolean parse(String  &input) {
    if(input == "*debug") {
        debug = true;
        return true;
    } else if(input == "*normal") {
        debug = false;
        return true;
    }
    return false;
}

/**
 * Function which outputs bus data via the serial port and MQTT.
 * Depending in debug mode, it may output more data.
 * 
 * In normal mode, it also checks the valid flag and only
 * outputs valid bus messages.
 * @param busmessage The bus message to be send out to the user.
*/
void output(GDOOR_DATA_PROTOCOL &busmessage, const char* topic, bool force=false) {
    if(force || debug || (busmessage.raw != NULL && busmessage.raw->valid)) {
        MQTT_HELPER::printer.print("{");
        MQTT_HELPER::printer.print(busmessage);
        MQTT_HELPER::printer.println("}");
        MQTT_HELPER::printer.publish((const char*)topic);
    }
}

void setup() {
    Serial.begin(115200);
    Serial.setTimeout(1);
    JSONDEBUG("GDoor Setup start");
    
    WIFI_HELPER::setup();
    MQTT_HELPER::setup(WIFI_HELPER::mqtt_server(),
                       WIFI_HELPER::mqtt_port(),
                       WIFI_HELPER::mqtt_user(),
                       WIFI_HELPER::mqtt_password(),
                       WIFI_HELPER::mqtt_topic_bus_tx(),
                       WIFI_HELPER::mqtt_topic_bus_rx());

    GDOOR::setRxThreshold(PIN_RX_THRESH, WIFI_HELPER::rx_sensitivity());
    GDOOR::setup(PIN_TX, PIN_TX_EN, WIFI_HELPER::rx_pin());

    mqtt_topic_bus_rx = WIFI_HELPER::mqtt_topic_bus_rx();
    debug = WIFI_HELPER::debug();

    JSONDEBUG("GDoor Setup done");
    JSONDEBUG("RX Pin: ");
    JSONDEBUG(WIFI_HELPER::rx_pin());
    JSONDEBUG("RX Sensitivity: ");
    JSONDEBUG(WIFI_HELPER::rx_sensitivity());
}

void loop() {
    WIFI_HELPER::loop();
    MQTT_HELPER::loop();
    GDOOR::loop();
    GDOOR_DATA* rx_data = GDOOR::read();

    // Output bus idle message on new MQTT connections to set a defined state
    if(MQTT_HELPER::isNewConnection()) {
        output(gdoor_data_idle, mqtt_topic_bus_rx, true);
    }
    if(rx_data != NULL) {
        JSONDEBUG("Received data from bus");
        GDOOR_DATA_PROTOCOL busmessage = GDOOR_DATA_PROTOCOL(rx_data);
        output(busmessage, mqtt_topic_bus_rx);
        JSONDEBUG("Output bus data via Serial and MQTT, done");
        // Output idle message after bus message, to reset values so that
        //home automation can trigger again
        output(gdoor_data_idle, mqtt_topic_bus_rx, true);

    } else if (!GDOOR::active()) { // Neither RX nor TX active,
        String str_received("");
        if (Serial.available() > 0) { // let's check the serial port if something is in buffer
            str_received = Serial.readString();
        } else {
            str_received = MQTT_HELPER::receive();
        }
        str_received.trim();    

        if(str_received.length() > 0) {
            if(!parse(str_received)) { //Check if received string is a command
                GDOOR::send(str_received); // Send to bus if it is not a command
                JSONDEBUG("Send: ");
                JSONDEBUG(str_received);
            }
        }
        
    }
}

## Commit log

2024-02-16 Add ugly stuff
    [LT1013DD.step, particle.cfg, stm32.kicad_pcb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]
2024-02-23 ESP32 version
    [esp32.kicad_pcb, esp32.kicad_sch]
2024-02-28 Rough untested, uncompiled ESP32 firmware. Just transfer from stm32 code
    [esp32.kicad_pcb, esp32.kicad_sch]
2024-02-28 Fix compile errors and move esp32 arduino API from v3 to v2
    [defines.h, gdoor_tx.cpp]
2024-02-28 Add ESP32 to README
2024-02-29 More robust RX for ESP32
2024-03-03 Make serial print easier for GDOOR_RX_DATA
2024-03-03 More comments for long statemachine brackets
2024-03-04 Json output, flash macro, timer defines
2024-03-07 add production data for jlcpcb
    [bom.csv, designators.csv, positions.csv]
2024-03-07 Add esp32 pictures
2024-03-07 add schematic as PDF
2024-03-07 Fix esp32 prescaler value for 60khz timer
    [defines.h]
2024-03-10 Revert back to normal Extint
    [gdoor_tx.cpp]
2024-03-12 More infos about current firmware
2024-03-12 Warn new users about current bug
2024-03-12 Document current hw hack
    [esp32.kicad_pcb]
2024-03-13 Start with next revision, which includes comparators
    [bom.csv, designators.csv, esp32.kicad_pcb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]
2024-03-19 Work on V3.1
    [esp32.kicad_pcb, esp32.kicad_sch]
2024-03-19 Mark boot pins and move rx pins to non boot pins
    [esp32.kicad_pcb, esp32.kicad_sch]
2024-03-24 Working on V3.1
    [esp32.kicad_pcb, esp32.kicad_sch]
2024-03-24 Add logo
    [esp32.kicad_pcb, esp32.kicad_sch]
2024-03-29 update lib
    [esp32.kicad_pcb]
2024-04-01 improve order of high level props
2024-04-01 remove _AUDIO type suffix since audio & video devices seem to have the same type
2024-04-08 Start to integrate MQTT and Arduino Serial Print, untested!
2024-04-08 Integrate print and MQTT, untested WIP.
2024-04-11 Not working intermediate step on wifi feature
    [defines.h, main.cpp]
2024-04-14 Comments and a small potenial bugfix in case of read issues
2024-04-15 Fix mqtt topics, set hostname, first local test done
    [main.cpp]
2024-04-16 Increase Printer Buffer size to 2048
2024-04-16 Revert "Change MQTT buffer size"
    This reverts commit 05fae5205ca5830b5178d39d46ddb624c362481a.
    [defines.h]
2024-04-17 Hide Serial print behind debug flag
2024-04-17 Fix #3, first action not received. Do not start TX timer on boot
    [gdoor_tx.cpp]
2024-04-17 V3.1: Add power filtering
    [esp32.kicad_pcb, esp32.kicad_sch]
2024-04-26 Add more debug prints
2024-04-28 missing new lines in debug logging
    [main.cpp]
2024-05-07 add 100k on hw v3.1
    [esp32.kicad_pcb, esp32.kicad_sch]
2024-05-16 Add v3.1 production data
    [bom.csv, designators.csv, positions.csv]
2024-05-16 Add v3.1 production data (missing file)
    [esp32.kicad_pcb]
2024-05-19 Start with framework for 3.1 options
2024-05-27 Fix bug in V3.1 wifimanager parameters
    [main.cpp]
2024-05-27 Fix wrong v3.1 merge
    [main.cpp]
2024-06-19 Release HW3.1-1
    Changed bus connector due to JLCPCB availability
    [esp32.kicad_pcb, esp32.kicad_sch, screwterminal_3_5mm_2.STEP]
2024-06-23 Only set dev if not already defined to avoid compiler warning
    [defines.h]

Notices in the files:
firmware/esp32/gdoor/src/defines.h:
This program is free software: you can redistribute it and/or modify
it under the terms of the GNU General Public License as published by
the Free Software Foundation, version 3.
